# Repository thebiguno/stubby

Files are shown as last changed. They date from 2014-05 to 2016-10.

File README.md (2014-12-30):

Stubby
======

Source Code for Stubby the Hexapod (http://stubby.digitalcave.ca/stubby/ or http://hackaday.io/project/770)

Repository includes AVR source code, KiCAD schematics + routed PCBs, frame design (.dxf for cutting on a scroll saw, laser cutter, CNC, etc), python programs for calibration and control, etc.  Please visit the web pages for more information and build instructions.

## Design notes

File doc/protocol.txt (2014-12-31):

Protocol Info
-------------

Message Structure (bi-directional):
Segment				Length
---------------------------------
Frame start			1 byte (0x7e)
Length				1 byte
Command				1 byte
Payload				0 - 254 bytes
Checksum			1 byte

Commands:
---------
There are four logical message types: 
1) PC initiates a message to Stubby
2) Stubby responds to a message from PC
3) Stubby initiates a message to PC
4) PC responds to a message from Stubby

Message types 1 and 2 comprise the majority of communication.  Message 
types 3 and 4 imply an event-driven programming model.  Initially, we 
do not want to do this as it adds complexity to the new programmer,
however we do not want to preclude this from being added at a later 
date.

Commands have a variable payload.  A description of payloads is below.
Portions in [square brackets] are optional.

Command						Direction				Payload																				Response
-------------------------------------------------------------------------------------------------------------------------------------------------------------
-- General commands
AnnounceControlId			Control -> Stubby		Controller ID; UC = 0x55 ('U'), Processing = 0x50 ('P'), Calibration = 'C', etc		None
SendAcknowledge				Stubby -> Control		Command being ack'd (1 byte)														None
SendComplete				Stubby -> Control		Command completed (1 byte)															None

RequestEnableDebug			Control -> Stubby		Null																				Ack
RequestDisableDebug			Control -> Stubby		Null																				Ack
SendDebug					Stubby -> Control		Variable depending on message, max 254 bytes										None

RequestBattery				Control -> Stubby		Null																				Battery message
SendBattery					Stubby -> Control		1 byte																				None

-- Universal Controller commands
UCButtonPush				Control -> Stubby		Index of button which was just pressed (1 byte)										None
UCButtonRelease				Control -> Stubby		Index of button which was just released (1 byte)									None
UCJoystickMove				Control -> Stubby		Value of all joystick axis (4 bytes, order LX:LY:RX:RY)								None

-- Processing API commands
RequestPowerOn				Control -> Stubby		Null																				Ack
RequestPowerOff				Control -> Stubby		Null																				Ack

RequestMove					Control -> Stubby		Angle (1 byte), Velocity (1 byte), Distance (2 bytes)								Ack + Complete when done
RequestTurn					Control -> Stubby		Angle (1 bytes), Velocity (1 byte)													Ack + Complete when done
RequestTranslate			Control -> Stubby		Amount (3 bytes, order X, Y, Z)														Ack
RequestRotate				Control -> Stubby		Axis (1 byte), Angle (1 byte)														Ack

RequestHeading				Control -> Stubby		Null																				Heading message
SendHeading					Stubby -> Control		Angle (1 byte)																		None

RequestDistance				Control -> Stubby		Null																				Distance message
SendDistance				Stubby -> Control		Distance (2 bytes, MSB first)																	None

RequestOptical				Control -> Stubby		Null																				Optical message
SendOptical					Stubby -> Control		1 byte / sensor (TODO: How many sensors?)											None

RequestSetLED				Control -> Stubby		3 bytes (RGB value)																	Ack

-- Calibration program commands
RequestJointCalibration		Control -> Stubby		Null																				SendJointCalibration message
SendJointCalibration		Either -> Either		18 bytes, ordered LEG0_TIBIA, LEG0_FEMUR, LEG0_COXA, ... LEG5_COXA					None

RequestFootCalibration		Control -> Stubby		Null																				SendFootCalibration message
SendFootCalibration			Either -> Either		18 bytes, ordered LEG0_X, LEG0_Y, LEG0_Z, LEG1_X, ... LEG5_Z						None

RequestMagnetometerCalibration	Control -> Stubby	Null																				SendMagnetometerCalibration message
SendMagnetometerCalibration	Either -> Either		4 bytes (two 16 bit signed integers, MSB first): X offset, Y offset					None
StartMagnetometerCalibration	Control -> Stubby	Null																				Repeated SendMagnetometerCalibration messages

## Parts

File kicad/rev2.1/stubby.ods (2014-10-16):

Id | Designator | Package | Quantity | Designation | Supplier and ref | Unit Cost | Ext Cost | Comments
1 | C17 | C1V8 | 1 | 15000µF | 493-1013-ND | $1.8300 | $1.83
2 | VR3,VR1 | SOT23 | 2 | MCP1702 | MCP1702T-3302E/CBCT-ND | $0.7000 | $1.40
3 | P5,P10 | Male Headers, right angle | 1 |  | S1112E-10-ND | $1.1300 | $1.13 | Digikey is expensive, I get mine in bulk from eBay
4 | P1,P2 | Female Headers, 6 position | 3 | CONN_6 | S7004-ND | $0.8200 | $2.46 | One needed for Xbee and one for Bluetooth
5 | P3 | SIL-10 | 1 | CONN_10 | S5751-10-ND | $1.4800 | $1.48 | Only needed if using Xbee
6 | ZD1 | SOT23 | 1 | ZD 3v3 | BZX84C3V3-FDICT-ND | $0.2000 | $0.20
7 | SW2 | DPDT | 1 | DPDT | 360-2804-ND | $3.7400 | $3.74
8 | S4-S7, P11,JP1,P6,P8 | N/A | 2 | Male headers (straight) | S1011EC-34-ND | $0.8400 | $1.68 | We need about 70 pins total. Digikey is expensive, I get mine in bulk from eBay
9 | IC1 | TQFP44 | 1 | ATMEGA1284-A | ATMEGA1284-AU-ND | $9.2100 | $9.21
10 | R4,R7,R3,R8,R10,R9,R1,R2 | SM0603 | 8 | 1k | 311-1.0KGRCT-ND | $0.0140 | $0.11
11 | C7,C8 | SM0603 | 2 | 20pF | 1276-1187-1-ND | $0.1200 | $0.24
12 | C5,C4,C3,C12,C16,C13,C14,C19 | SM0603 | 8 | 1uF | 587-1242-1-ND | $0.1200 | $0.96
13 | R5,R6 | SM0603 | 2 | 100k | 311-100KGRCT-ND | $0.0140 | $0.03
14 | D2 | LED-0805-MARKED_ANODE | 1 | LED | 475-2832-1-ND | $0.2700 | $0.27
15 | VR2 | SOT23-5 | 1 | NCP1400A | NCP1400ASN50T1GOSCT-ND | $0.9900 | $0.99
16 | C10,C15 | SM1206POL | 2 | 47uF | ATCC-211A-006-476M-TCT-ND | $0.4900 | $0.98
17 | C1 | SM0805 | 1 | 10uF | 1276-3012-1-ND | $0.1900 | $0.19
18 | D1 | POWERDI_123 | 1 | DFLS130L | DFLS130LDICT-ND | $0.5900 | $0.59
19 | L1 | SM1007 | 1 | 22uH | 587-2439-1-ND | $0.3500 | $0.35
20 | D3 | 4-PLCC | 1 | CLVBA-FKA | CLVBA-FKA-CAEDH8BBB7A363CT-ND | $0.6600 | $0.66
21 | SW1 | sw_42_32 | 1 | SW_PUSH | CKN10502CT-ND | $0.3600 | $0.36
22 | X1 | CRYSTAL_SMD_5x3.2 | 1 | CRYSTAL | CTX1164CT-ND | $0.7600 | $0.76
23 | C6 | SM0603 | 1 | 4.7uF | 490-3297-1-ND | $0.1400 | $0.14
24 | C9 | SM0603 | 1 | 0.22uF | 445-1318-1-ND | $0.1200 | $0.12
25 | U1 | LPCC-16 | 1 | HMC5883L | 342-1082-1-ND | $4.2400 | $4.24
26 | C2 | C1V7 | 1 | 2200uF+ | UHM0J222MPD6-ND | $0.5900 | $0.59
27 | C11 | C1V5 | 1 | 470uF | 399-6611-ND | $0.2700 | $0.27
28 | N/A | HC-SR04 Distance Sensor | 1 | N/A | eBay | $2.0000 | $2.00 | Not on Digikey, I got mine on eBay for under $2
 | Total |  |  |  |  |  | $36.98 | Quantity 1 Robot

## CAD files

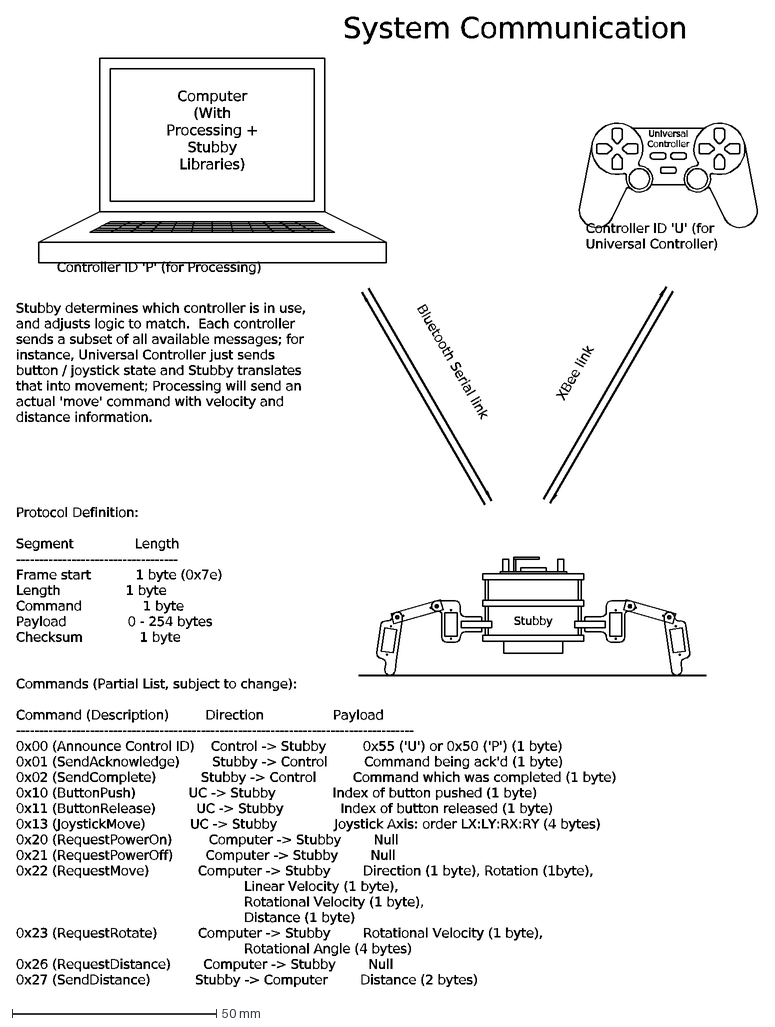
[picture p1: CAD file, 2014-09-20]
doc/System Overview.dxf
Universal Controller
Computer (With Processing + Stubby Libraries)
Stubby
Protocol Definition: Segment Length ----------------------------------- Frame start 1 byte (0x7e) Length 1 byte Command 1 byte Payload 0 - 254 bytes Checksum 1 
Controller ID 'P' (for Processing)
Controller ID 'U' (for Universal Controller)
Bluetooth Serial link
XBee link
Stubby determines which controller is in use, and adjusts logic to match. Each controller sends a subset of all available messages; for instance, Universal Cont
System Communication

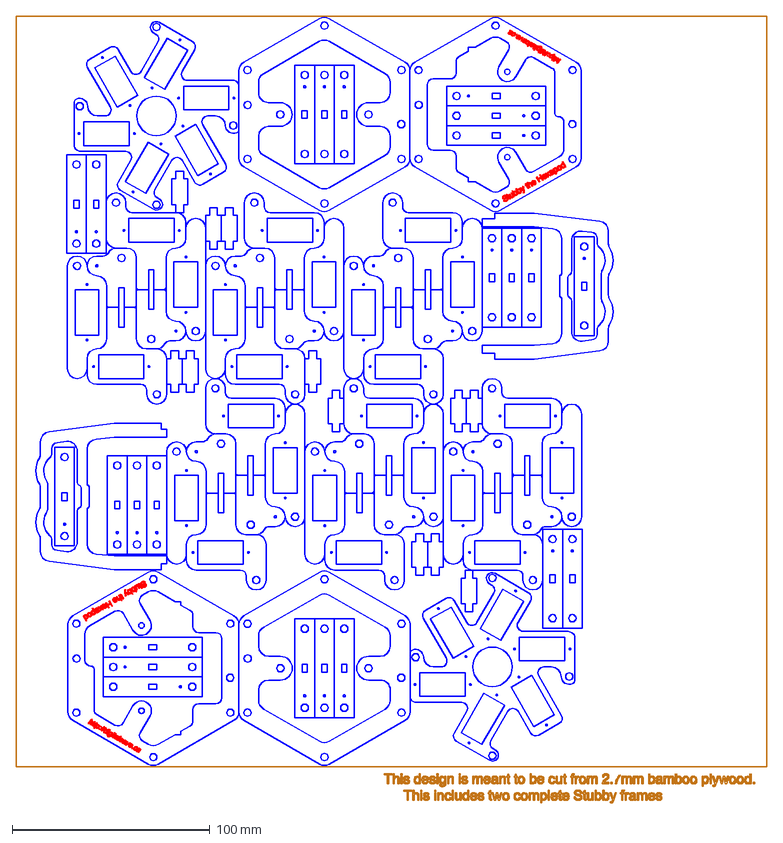
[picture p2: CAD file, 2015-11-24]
frame/frame_3dof_radial_laser.dxf
380.0 x 398.3 mm

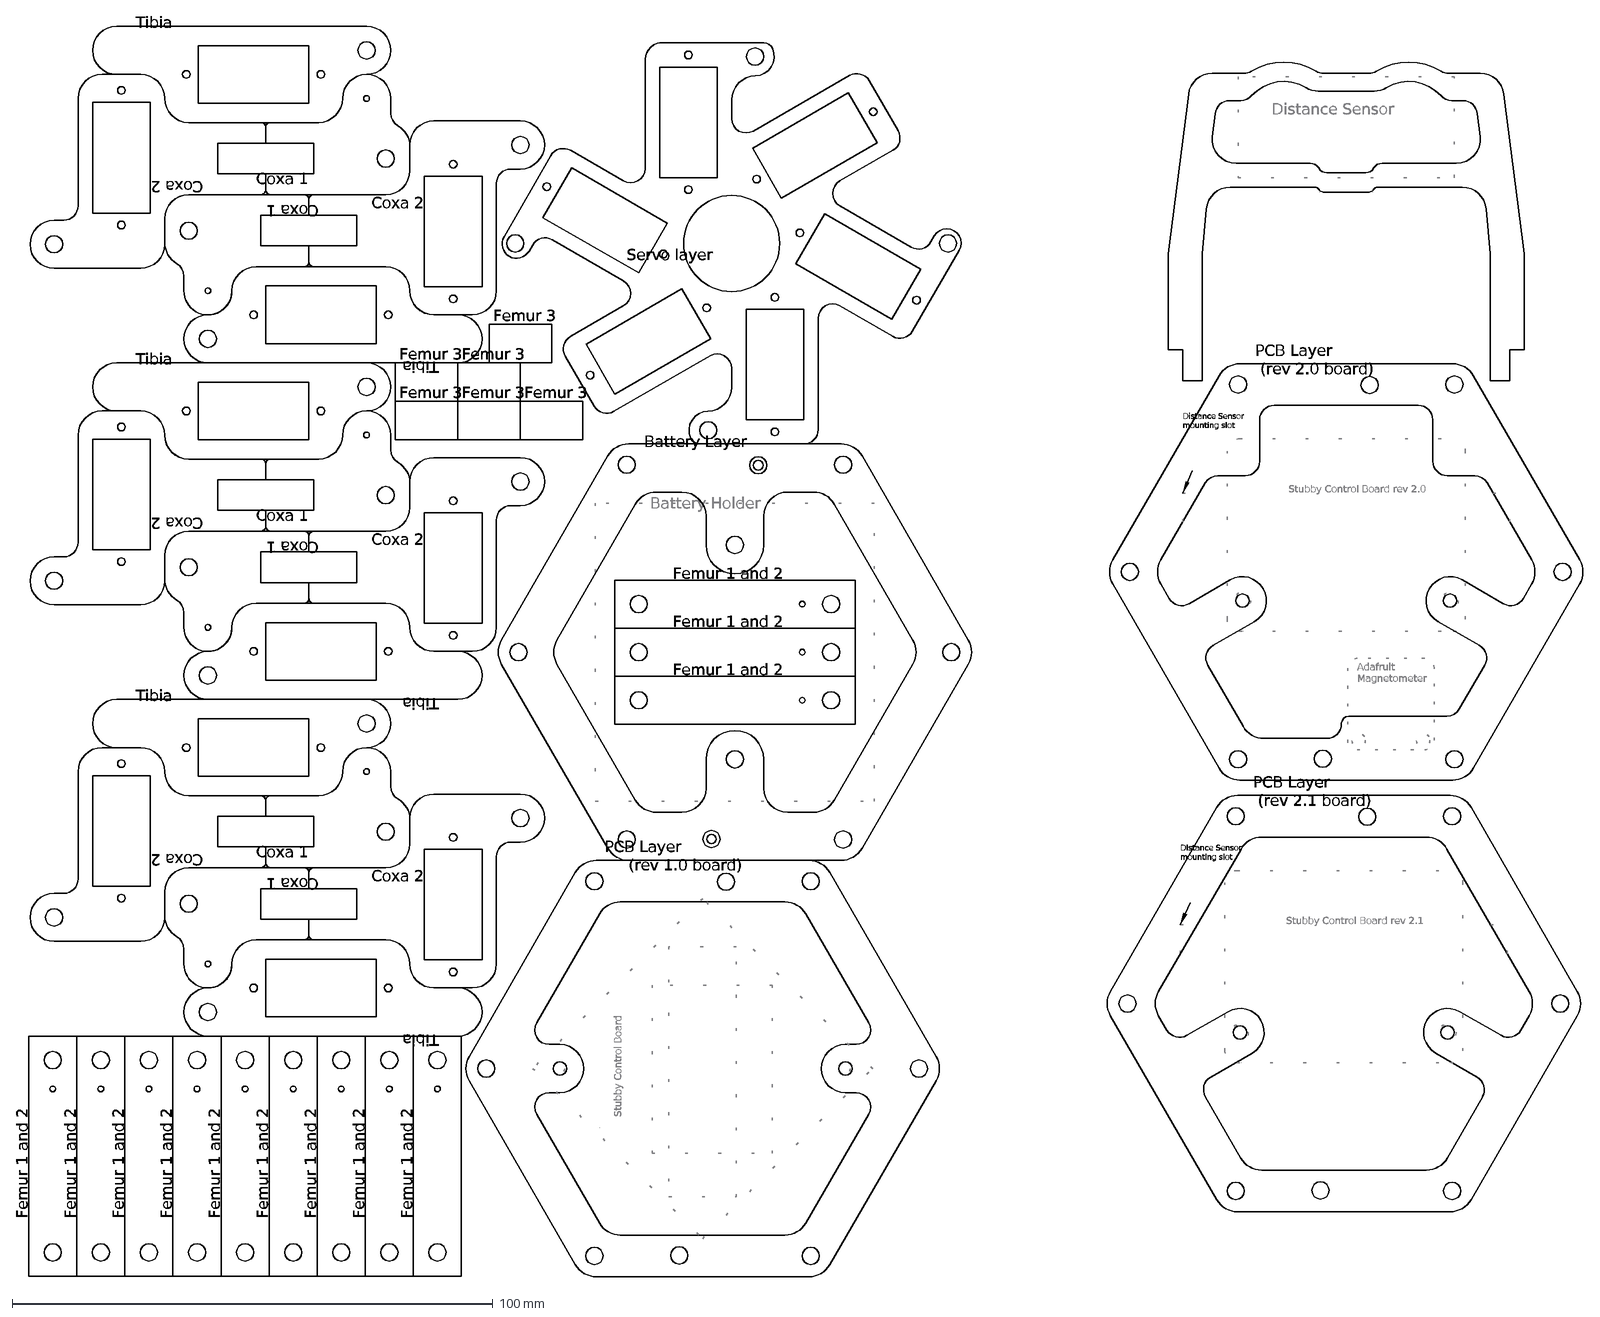
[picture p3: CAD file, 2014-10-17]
frame/frame_3dof_radial.dxf
Femur 1 and 2
Coxa 1
Coxa 2
Tibia
PCB Layer (rev 1.0 board)
Battery Holder
Battery Layer
Servo layer
Femur 3
PCB Layer (rev 2.0 board)
Stubby Control Board rev 2.0
Adafruit Magnetometer
Distance Sensor mounting slot
Distance Sensor
Stubby Control Board
PCB Layer (rev 2.1 board)
Stubby Control Board rev 2.1

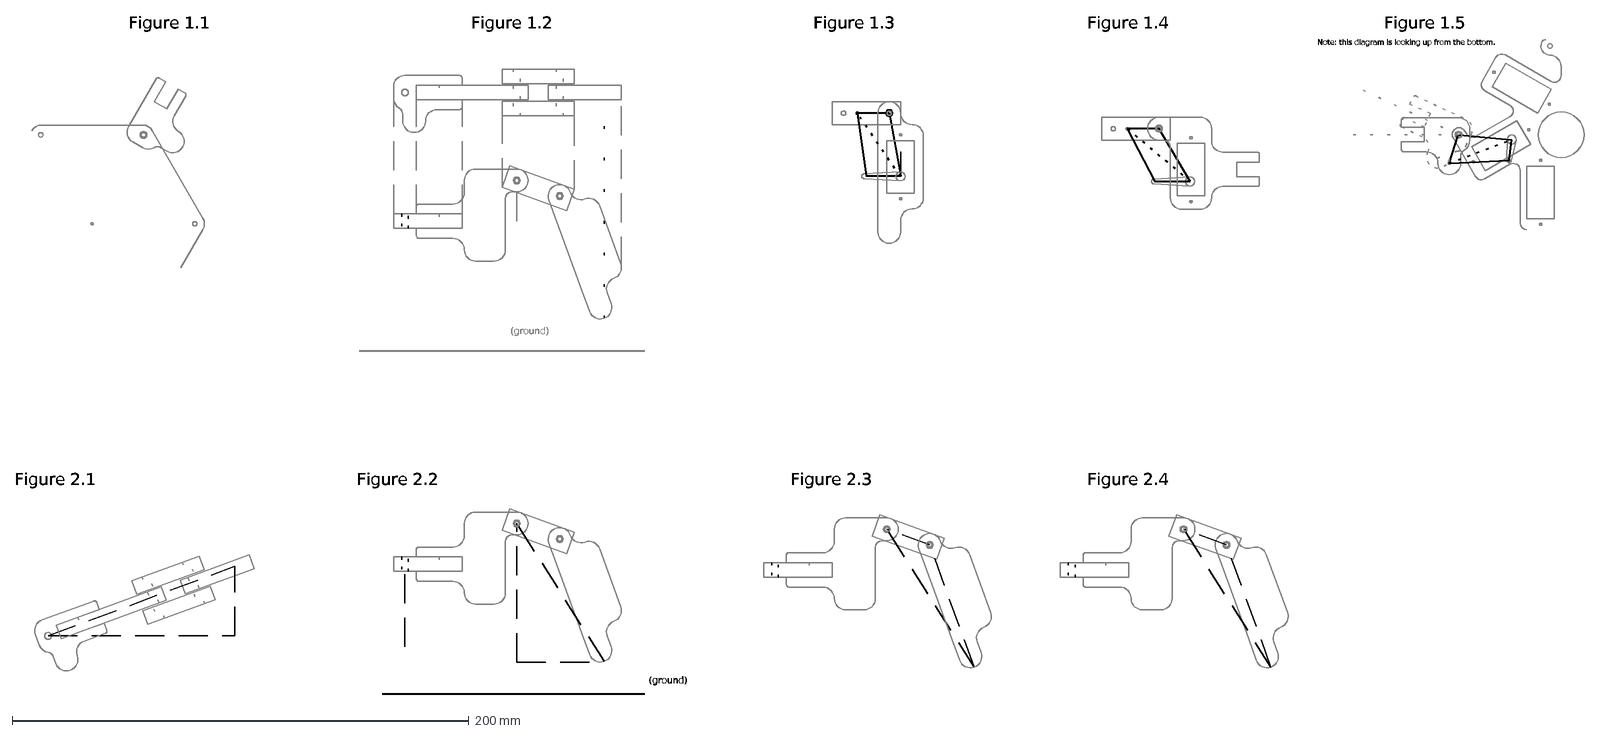
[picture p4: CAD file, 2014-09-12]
frame/frame_3dof_radial_diagrams.dxf
Figure 1.1
(ground)
Figure 1.2
Figure 1.3
Figure 1.4
Figure 2.1
Figure 2.2
Figure 2.3
Figure 2.4
Figure 1.5
Note: this diagram is looking up from the bottom.

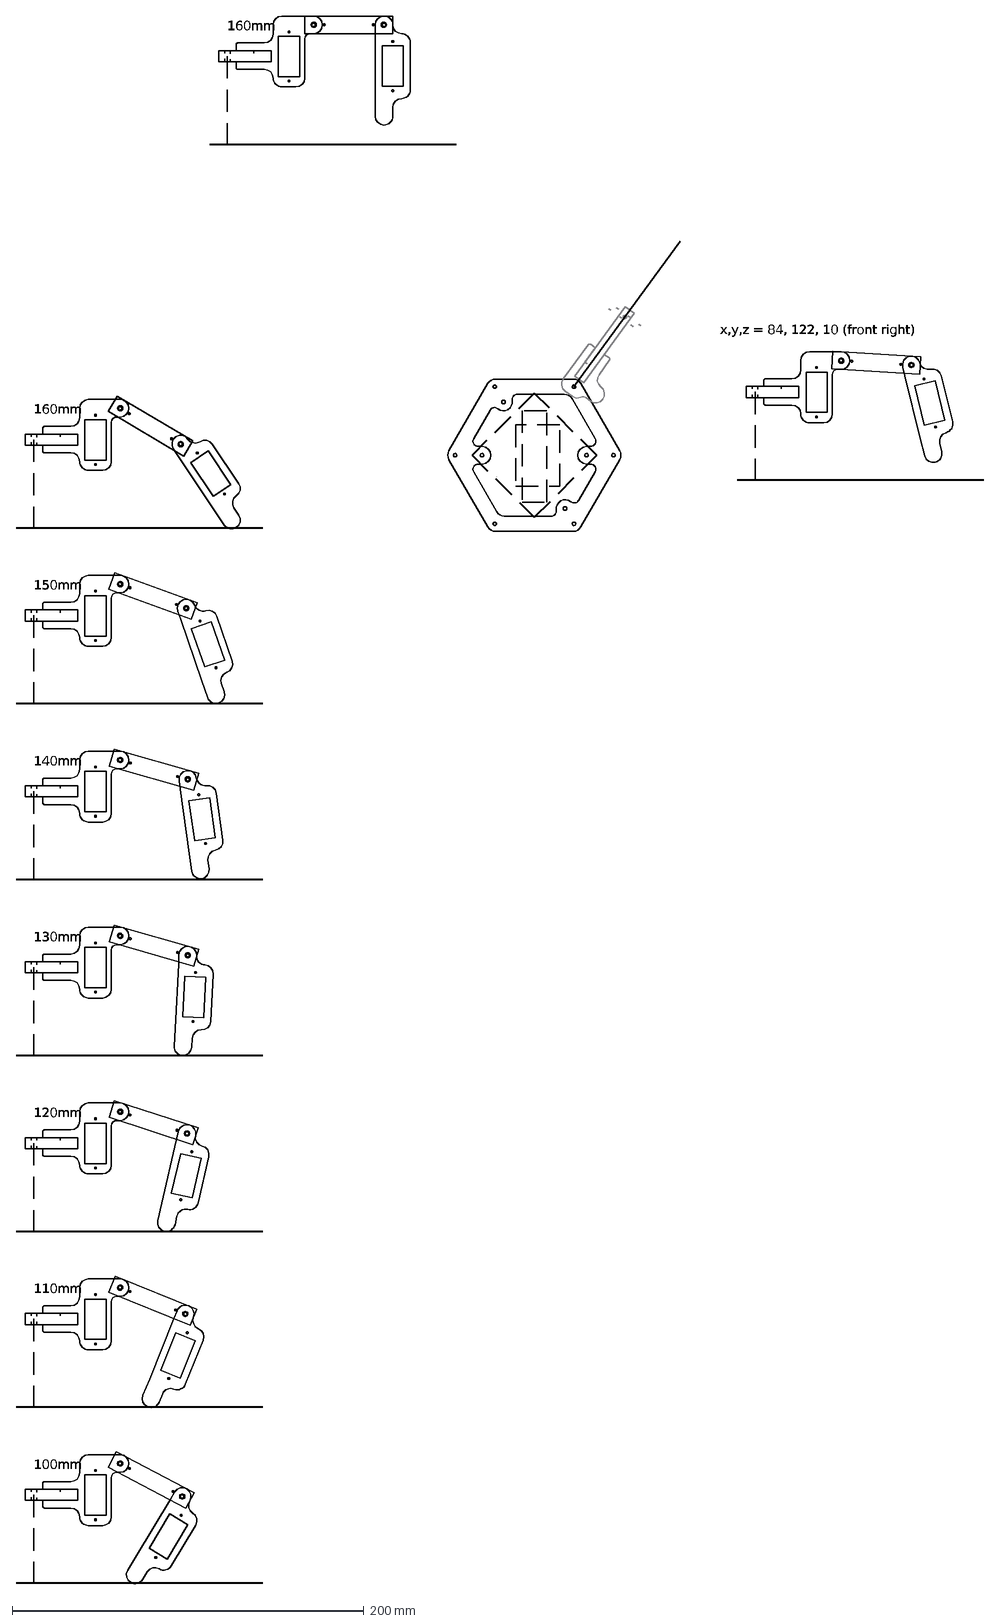
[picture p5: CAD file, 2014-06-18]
frame/frame_3dof_radial_simulation.dxf
150mm
140mm
130mm
120mm
110mm
100mm
160mm
x,y,z = 84, 122, 10 (front right)

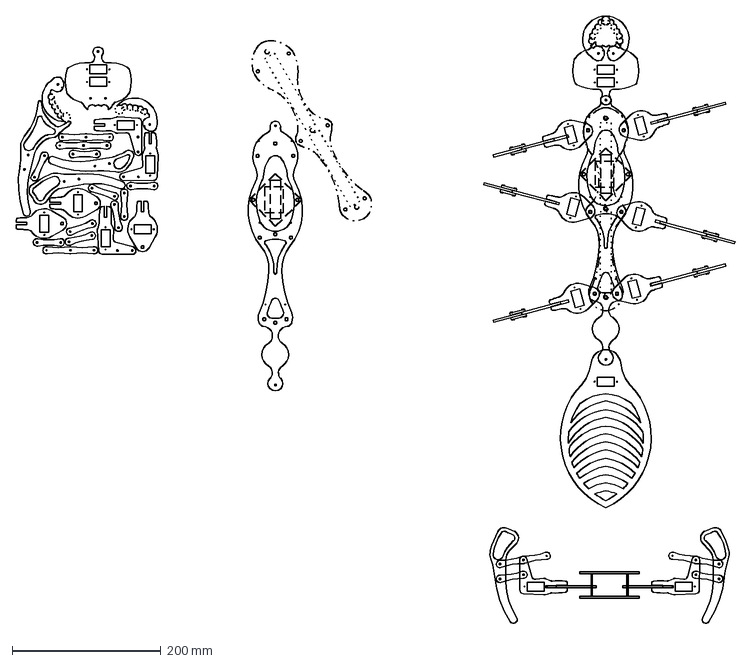
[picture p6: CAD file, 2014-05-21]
frame/frame_2dof_insect.dxf
968.1 x 818.4 mm

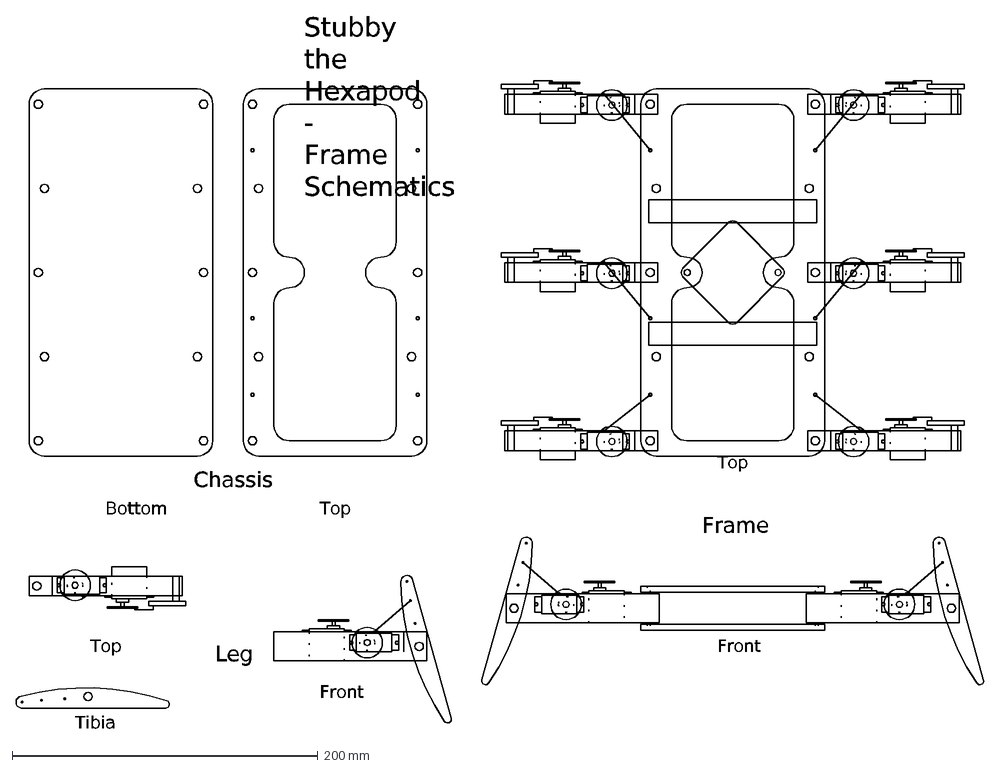
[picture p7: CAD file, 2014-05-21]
frame/frame_2dof_simple.dxf
Chassis
Top
Bottom
Leg
Front
Frame
Tibia
Stubby the Hexapod - Frame Schematics

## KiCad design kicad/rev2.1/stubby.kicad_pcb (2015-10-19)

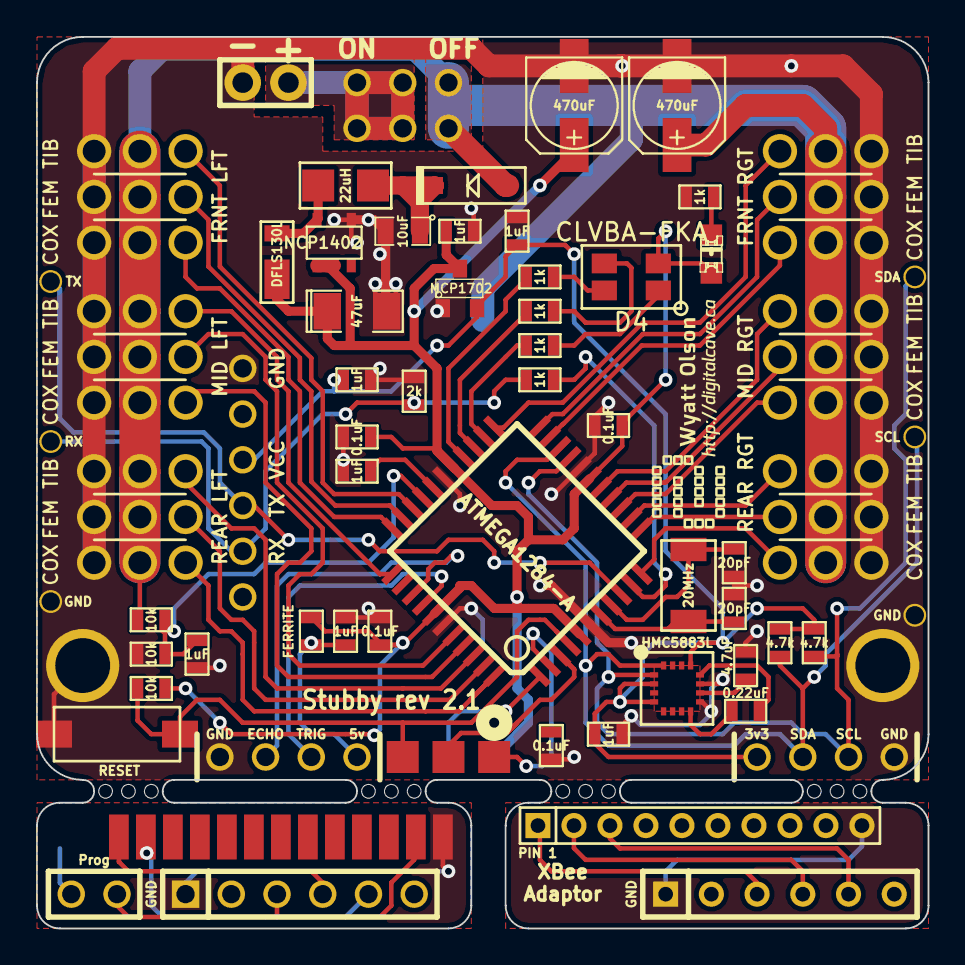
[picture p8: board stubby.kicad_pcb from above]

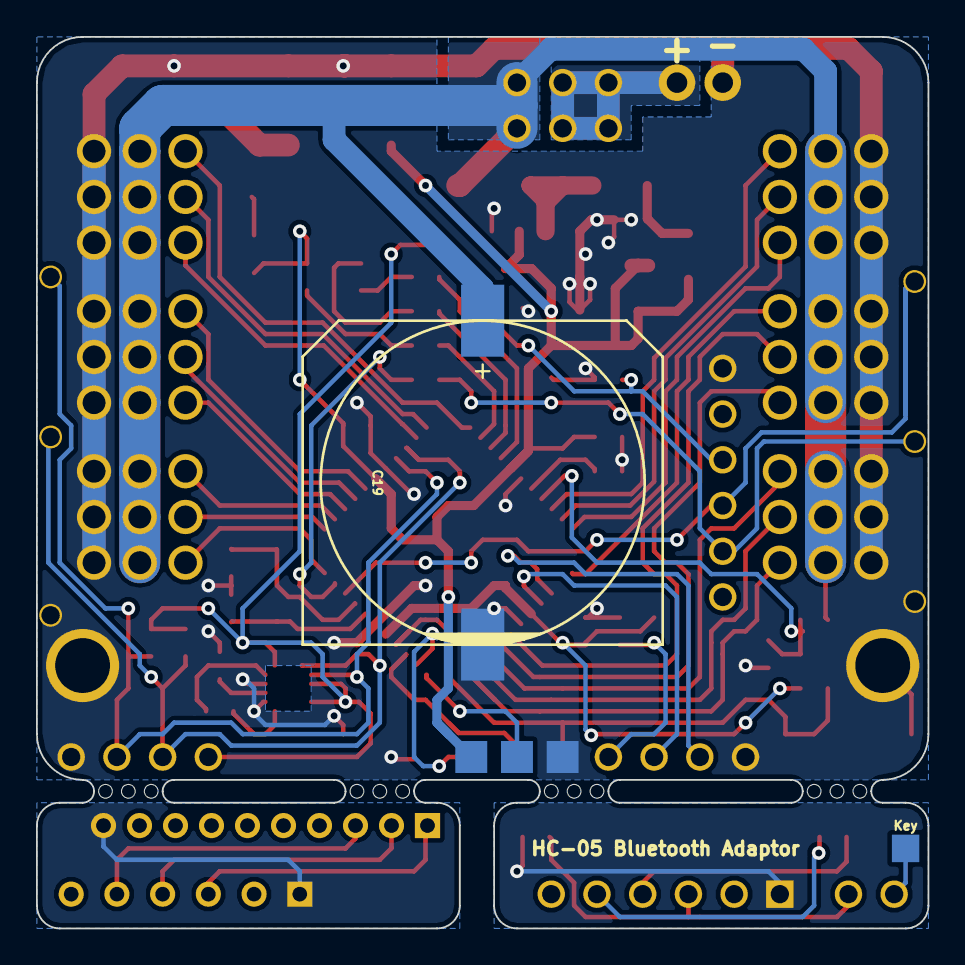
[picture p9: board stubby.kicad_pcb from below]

Board: 2 copper layers, 49.5 x 49.5 mm, 74 parts (2 on the bottom side), 60 nets.

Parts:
1PIN, 1PIN#2, 1PIN#3, 1PIN#4, 1PIN#5, 1PIN#6, 1PIN#7, 1PIN#8: P***; 1pin
C1: 10uF; SM0805
C2, C3, C6, C15, C16, C17, C18: 1uF; SM0603_VALUE
C4: 47uF; SM1206POL
C5, C20: 470uF; c_elec_5x5.3
C7: 4.7uF; SM0603_VALUE
C8, C9: 20pF; SM0603_VALUE
C10: 0.22uF; SM0603_VALUE
C11, C12, C13, C14: 0.1uF; SM0603_VALUE
C19: 6800µF; c_elec_18x18
D1: 1N4148W; SOD-123_DIODE
D2: DFLS130L; POWERDI_123
D3: LED; LED-0805-MARKED_ANODE
D4: CLVBA-FKA; 4-PLCC
IC1: ATMEGA1284-A; TQFP44
L1: 22uH; SM1007
L2: FERRITE; SM0603_VALUE
P1, P6, P11: CONN_6; SIL-6
P2, P10: CONN_4; SIL-4
P3: CONN_13; HC05_Edge
P4: CONN_2; SIL-2
P5: CONN_1; SIL-1
P7: CONN_10; SIL-10
P8: BATT (4.8V-6V); SIL-2
P9: PROG; ISP_EDGE
R1, R2: 4.7k; SM0603_VALUE
R3, R5, R6: 10k; SM0603_VALUE
R4, R7, R9, R10, R11: 1k; SM0603_VALUE
R8: 2k; SM0603_VALUE
S1: FRNT LFT; HEX_LEG
S2: FRNT RGT; HEX_LEG_REVERSE
S3: MID LFT; HEX_LEG
S4: MID RGT; HEX_LEG_REVERSE
S5: REAR LFT; HEX_LEG
S6: REAR RGT; HEX_LEG_REVERSE
SW1: SW_PUSH; SW_6x3
SW2: DPDT
U1: HMC5883L; LPCC-16
VAL: DIGITALCAVE_LOGO_WIDE_SMALL
VR1: MCP1702; SOT23
VR2: NCP1402; SOT23-5
X1: 20MHz; CRYSTAL_SMD_5x3.2
mouse_bites: VAL**; mouse_bites
mouse_bites#2, mouse_bites#3, mouse_bites#4: VAL**; mouse_bites

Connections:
+3.3V: C2.1, C15.1, C18.2, P2.1, P11.3, R1.2, R2.2, U1.2, U1.4, U1.13, VR1.3
+5V: C3.1, C4.1, C5.1, C11.1, C12.1, C13.1, D2.2, D3.1, D4.2, IC1.5, IC1.17, IC1.27, IC1.38, L2.2, P9.2, R3.1, VR1.2, VR2.1, VR2.2
+BATT: C19.1, C20.1, D1.1, R5.1, S1.4, S1.5, S1.6, S2.4, S2.5, S2.6, S3.4, S3.5, S3.6, S4.4, S4.5, S4.6, S5.4, S5.5, S5.6, S6.4, S6.5, S6.6, SW2.3, SW2.6
/ADC_BATTERY_METER: C16.2, IC1.30, R5.2, R6.2
/AREF: C6.2, IC1.29
/AVR_RX: 1PIN#6.1, IC1.9, P11.4
/AVR_TX: IC1.10, R7.1
/BATTERY: P8.1, SW2.1, SW2.2, SW2.4, SW2.5
/BLUETOOTH_GND: P1.1, P3.13
/DIST_ECHO: IC1.36, P10.3
/DIST_TRIG: IC1.37, P10.2
/I2C_SCL: 1PIN#3.1, IC1.19, P2.3, R1.1, U1.1
/I2C_SDA: 1PIN#2.1, IC1.20, P2.2, R2.1, U1.16
/LED_BL: IC1.25, R10.1
/LED_BL_R: D4.3, R10.2
/LED_GR: IC1.26, R9.1
/LED_GR_R: D4.4, R9.2
/LED_RD: IC1.24, R11.1
/LED_RD_R: D4.1, R11.2
/MISO: IC1.2, P9.1
/MODULE_RX: 1PIN#5.1, P11.5, R7.2, R8.2
/MOSI: IC1.1, P9.4
/PWM00: IC1.33, S1.1
/PWM01: IC1.32, S1.2
/PWM02: IC1.31, S1.3
/PWM03: IC1.23, S2.1
/PWM04: IC1.22, S2.2
/PWM05: IC1.21, S2.3
/PWM06: IC1.41, S3.1
/PWM07: IC1.40, S3.2
/PWM08: IC1.34, S3.3
/PWM09: IC1.16, S4.1
/PWM10: IC1.15, S4.2
/PWM11: IC1.14, S4.3
/PWM12: IC1.44, S5.1
/PWM13: IC1.43, S5.2
/PWM14: IC1.42, S5.3
/PWM15: IC1.13, S6.1
/PWM16: IC1.12, S6.2
/PWM17: IC1.11, S6.3
/RESET: IC1.4, P9.5, R3.2, SW1.2
/SCK: IC1.3, P9.3
/XBEE_GND: P6.1, P7.10
/XTAL1: C9.2, IC1.8, X1.1
/XTAL2: C8.2, IC1.7, X1.2
GND: 1PIN.1, 1PIN#4.1, 1PIN#7.1, 1PIN#8.1, C1.2, C2.2, C3.2, C4.2, C5.2, C6.1, C7.2, C8.1, C9.1, C11.2, C12.2, C13.2, C14.2, C15.2, C16.1, C17.2, C18.1, C19.2, C20.2, IC1.6, IC1.18, IC1.28, IC1.39, P2.4, P8.2, P9.6, P10.4, P11.1, R4.1, R6.1, R8.1, S1.7, S1.8, S1.9, S2.7, S2.8, S2.9, S3.7, S3.8, S3.9, S4.7, S4.8, S4.9, S5.7, S5.8, S5.9, S6.7, S6.8, S6.9, SW1.1, U1.9, U1.11, VR1.1, VR2.4
unnamed: C7.1, U1.10
unnamed: C10.1, U1.8
unnamed: C10.2, U1.12
unnamed: D2.1, L1.2, VR2.5
unnamed: C1.1, D1.2, L1.1
unnamed: C17.1, L2.1, P10.1
unnamed: D3.2, R4.2
unnamed: P6.3, P7.1
unnamed: P6.4, P7.2
unnamed: P6.5, P7.3
unnamed: P1.5, P3.2
unnamed: P4.1, P5.1
unnamed: P1.4, P3.1
unnamed: P1.3, P3.12, P4.2

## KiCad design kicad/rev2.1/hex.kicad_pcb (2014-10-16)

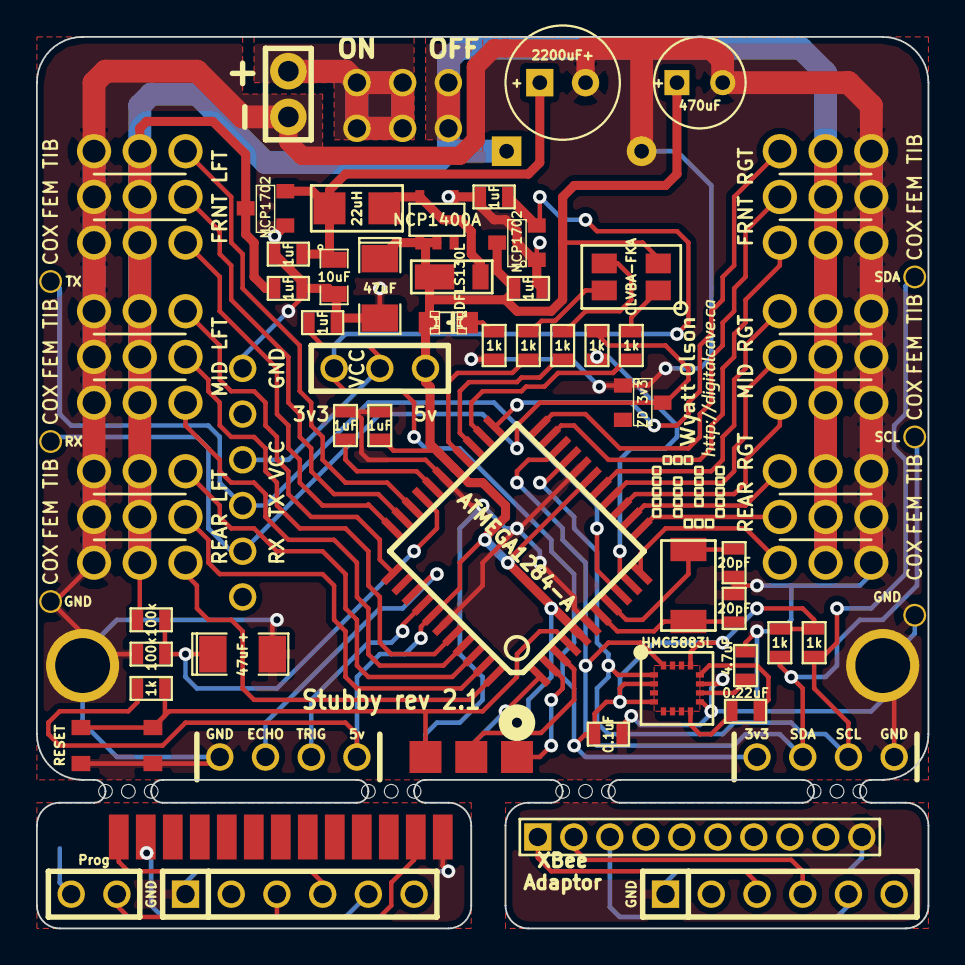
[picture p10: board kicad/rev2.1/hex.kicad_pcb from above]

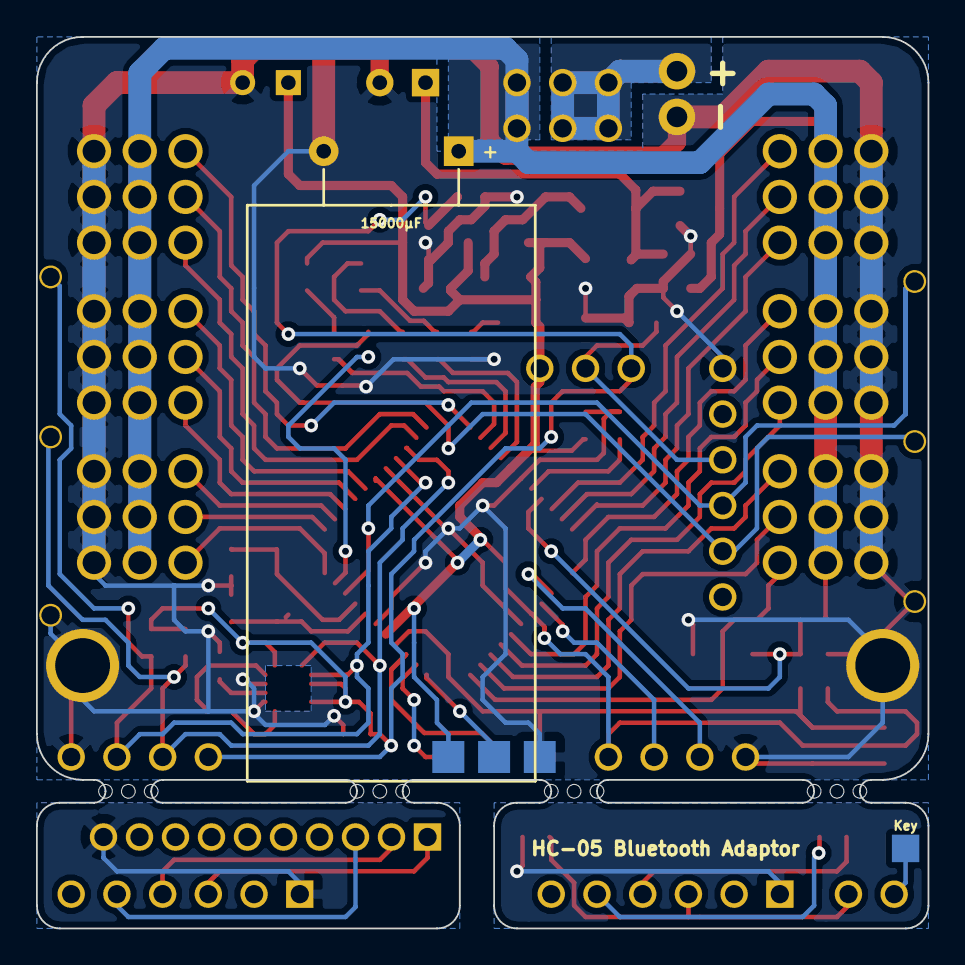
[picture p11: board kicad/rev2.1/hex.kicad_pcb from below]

Board: 2 copper layers, 49.5 x 49.5 mm, 72 parts (2 on the bottom side), 60 nets.

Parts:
1PIN, 1PIN#2, 1PIN#3, 1PIN#4, 1PIN#5, 1PIN#6, 1PIN#7, 1PIN#8: P***; 1pin
C1: 10uF; SM0805
C2: 2200uF+; C1V7
C3, C4, C5, C12, C13, C14, C16: 1uF; SM0603_VALUE
C6: 4.7uF; SM0603_VALUE
C7, C8: 20pF; SM0603_VALUE
C9: 0.22uF; SM0603_VALUE
C10: 47uF; SM1206POL
C11: 470uF; C1V5
C15: 47uF+; SM1206POL
C17: 15000µF; C1V8
C19: 0.1uF; SM0603_VALUE
D1: DFLS130L; POWERDI_123
D2: LED; LED-0805-MARKED_ANODE
D3: CLVBA-FKA; 4-PLCC
IC1: ATMEGA1284-A; TQFP44
JP1: CONN_3; SIL-3
L1: 22uH; SM1007
P1, P2, P11: CONN_6; SIL-6
P3: CONN_10; SIL-10
P4: CONN_13; HC05_Edge
P5, P10: CONN_4; SIL-4
P6: CONN_2; SIL-2
P7: CONN_1; SIL-1
P8: BATT (4.8V-6V); SIL-2
P9: PROG; ISP_EDGE
R1, R2, R3, R4, R7, R8, R9, R10: 1k; SM0603_VALUE
R5, R6: 100k; SM0603_VALUE
S2: FRNT LFT; HEX_LEG
S3: FRNT RGT; HEX_LEG_REVERSE
S4: MID LFT; HEX_LEG
S5: MID RGT; HEX_LEG_REVERSE
S6: REAR LFT; HEX_LEG
S7: REAR RGT; HEX_LEG_REVERSE
SW1: SW_PUSH; sw_42_32
SW2: DPDT
U1: HMC5883L; LPCC-16
VAL: DIGITALCAVE_LOGO_WIDE_SMALL
VR1, VR3: MCP1702; SOT23
VR2: NCP1400A; SOT23-5
X1: CRYSTAL; CRYSTAL_SMD_5x3.2
ZD1: ZD 3v3; SOT23
mouse_bites: VAL**; mouse_bites
mouse_bites#2, mouse_bites#3, mouse_bites#4: VAL**; mouse_bites

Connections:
+3.3V: C13.1, C19.1, JP1.3, P5.1, R1.2, R2.2, U1.2, U1.4, U1.13, VR3.3
+5V: C10.1, C11.1, C12.2, C14.1, D1.2, D2.1, D3.2, IC1.5, IC1.17, IC1.27, IC1.38, JP1.1, P9.2, P10.1, R3.1, VR2.1, VR2.2, VR3.2
+BATT: C4.1, C17.1, R5.1, S2.4, S2.5, S2.6, S3.4, S3.5, S3.6, S4.4, S4.5, S4.6, S5.4, S5.5, S5.6, S6.4, S6.5, S6.6, S7.4, S7.5, S7.6, SW2.3, SW2.6, VR1.2
/ADC_BATTERY_METER: C15.1, IC1.30, R5.2, R6.2
/AREF: C5.2, IC1.29
/AVR_RX: 1PIN#6.1, IC1.9, P11.4
/AVR_TX: IC1.10, R7.1
/BATTERY: P8.1, SW2.1, SW2.2, SW2.4, SW2.5
/BLUETOOTH_GND: P2.1, P4.13
/DIST_ECHO: IC1.36, P10.3
/DIST_TRIG: IC1.37, P10.2
/I2C_SCL: 1PIN#3.1, IC1.19, P5.3, R1.1, U1.1
/I2C_SDA: 1PIN#2.1, IC1.20, P5.2, R2.1, U1.16
/LED_BL: IC1.25, R9.1
/LED_BL_R: D3.3, R9.2
/LED_GR: IC1.26, R8.1
/LED_GR_R: D3.4, R8.2
/LED_RD: IC1.24, R10.1
/LED_RD_R: D3.1, R10.2
/MISO: IC1.2, P9.1
/MODULE_RX: 1PIN#5.1, P11.5, R7.2, ZD1.2
/MOSI: IC1.1, P9.4
/PWM00: IC1.33, S2.1
/PWM01: IC1.32, S2.2
/PWM02: IC1.31, S2.3
/PWM03: IC1.23, S3.1
/PWM04: IC1.22, S3.2
/PWM05: IC1.21, S3.3
/PWM06: IC1.41, S4.1
/PWM07: IC1.40, S4.2
/PWM08: IC1.34, S4.3
/PWM09: IC1.16, S5.1
/PWM10: IC1.15, S5.2
/PWM11: IC1.14, S5.3
/PWM12: IC1.44, S6.1
/PWM13: IC1.43, S6.2
/PWM14: IC1.42, S6.3
/PWM15: IC1.13, S7.1
/PWM16: IC1.12, S7.2
/PWM17: IC1.11, S7.3
/RESET: IC1.4, P9.5, R3.2, SW1.2
/SCK: IC1.3, P9.3
/XBEE_GND: P1.1, P3.10
/XTAL1: C8.2, IC1.8, X1.1
/XTAL2: C7.2, IC1.7, X1.2
GND: 1PIN.1, 1PIN#4.1, 1PIN#7.1, 1PIN#8.1, C1.2, C2.2, C3.2, C4.2, C5.1, C6.2, C7.1, C8.1, C10.2, C11.2, C12.1, C13.2, C14.2, C15.2, C16.1, C17.2, C19.2, IC1.6, IC1.18, IC1.28, IC1.39, P5.4, P8.2, P9.6, P10.4, P11.1, R4.1, R6.1, S2.7, S2.8, S2.9, S3.7, S3.8, S3.9, S4.7, S4.8, S4.9, S5.7, S5.8, S5.9, S6.7, S6.8, S6.9, S7.7, S7.8, S7.9, SW1.1, U1.9, U1.11, VR1.1, VR2.4, VR3.1, ZD1.1
unnamed: P1.5, P3.3
unnamed: P1.4, P3.2
unnamed: P1.3, P3.1
unnamed: P2.5, P4.2
unnamed: P2.4, P4.1
unnamed: P2.3, P4.12, P6.2
unnamed: C16.2, JP1.2, P11.3
unnamed: D1.1, L1.2, VR2.5
unnamed: P6.1, P7.1
unnamed: C9.1, U1.8
unnamed: C9.2, U1.12
unnamed: D2.2, R4.2
unnamed: C6.1, U1.10
unnamed: C1.1, C2.1, C3.1, L1.1, VR1.3

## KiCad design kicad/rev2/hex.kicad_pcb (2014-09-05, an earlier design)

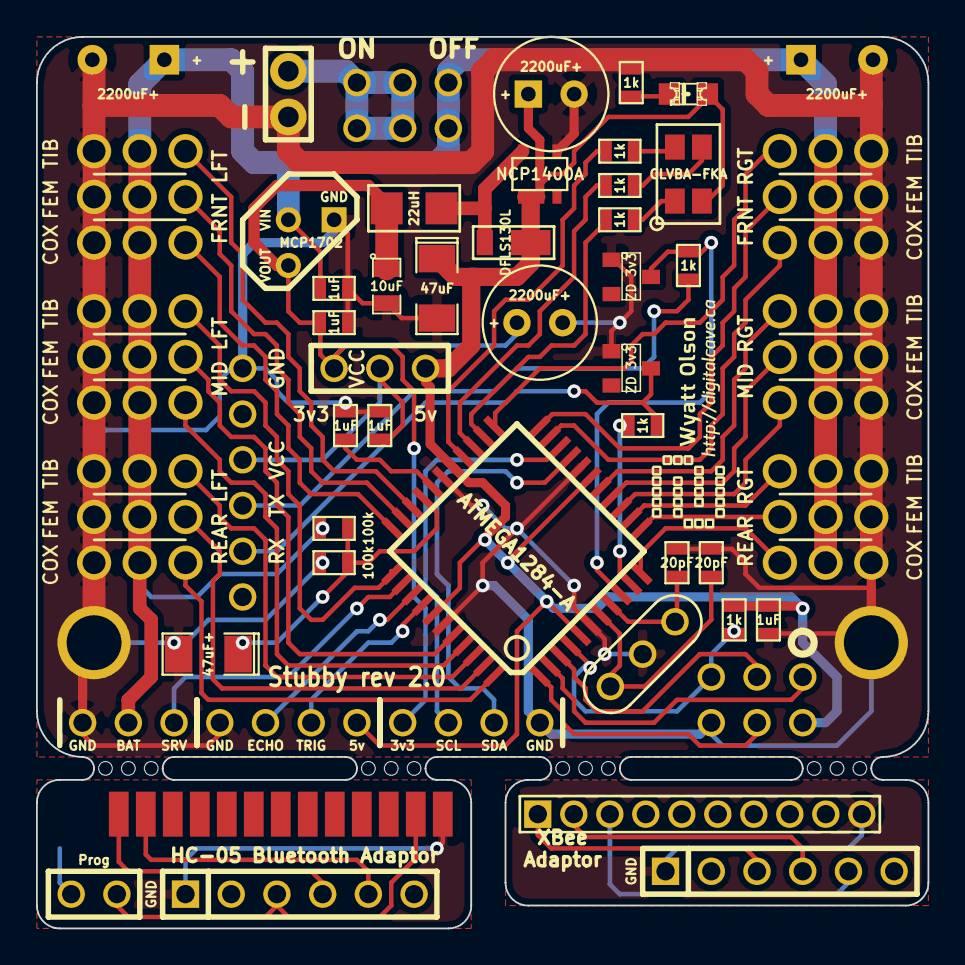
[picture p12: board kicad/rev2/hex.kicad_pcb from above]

Board: 2 copper layers, 49.5 x 49.5 mm, 60 parts (1 on the bottom side), 58 nets.

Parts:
1PIN, 1PIN#2: P***; 1pin
C1, C8: 2200uF+; C1V7
C2, C3, C9, C13, C14: 1uF; SM0603_VALUE
C4, C5: 2200uF+; C1V8
C6: 10uF; SM0805
C7: 47uF; SM1206POL
C10: 47uF+; SM1206POL
C11, C12: 20pF; SM0603_VALUE
D1: DFLS130L; POWERDI_123
D2: LED; LED-0805-MARKED_ANODE
D3: CLVBA-FKA; 4-PLCC
IC1: ATMEGA1284-A; TQFP44
JP1: CONN_3; SIL-3
L1: 22uH; SM1007
P1: BATT (4.8V-6V); SIL-2
P2: PROG; ISP
P3: CONN_10; SIL-10
P4, P6, P8: CONN_6; SIL-6
P5: CONN_13; HC05_Edge
P7: CONN_1; SIL-1
P9: CONN_2; SIL-2
P10, P11: CONN_4; SIL-4
R1, R4, R5, R6, R7, R8, R9: 1k; SM0603_VALUE
R2, R3: 100k; SM0603_VALUE
S1: FRNT LFT; HEX_LEG
S2: FRNT RGT; HEX_LEG_REVERSE
S3: MID LFT; HEX_LEG
S4: MID RGT; HEX_LEG_REVERSE
S5: REAR LFT; HEX_LEG
S6: REAR RGT; HEX_LEG_REVERSE
S7: CONN_3; SIL-3
SW1: DPDT
VAL: DIGITALCAVE_LOGO_WIDE_SMALL
VR1: MCP1702; TO92
VR2: NCP1400A; SOT23-5
X1: CRYSTAL_RESONATOR
ZD1, ZD2: ZD 3v3; SOT23
mouse_bites: VAL**; mouse_bites
mouse_bites#2, mouse_bites#3, mouse_bites#4: VAL**; mouse_bites

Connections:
+3.3V: C1.1, C2.1, C6.1, JP1.3, L1.1, P10.1, VR1.3
+5V: C7.1, C8.1, C9.2, D1.2, D2.1, D3.2, IC1.5, IC1.17, IC1.27, IC1.38, JP1.1, P2.2, P11.1, R4.1, VR2.1, VR2.2
+BATT: C3.1, C4.1, C5.1, R2.1, S1.4, S1.5, S1.6, S2.4, S2.5, S2.6, S3.4, S3.5, S3.6, S4.4, S4.5, S4.6, S5.4, S5.5, S5.6, S6.4, S6.5, S6.6, S7.2, SW1.3, SW1.6, VR1.2
/ADC_BATTERY_METER: C10.1, IC1.30, R2.2, R3.2
/AREF: C13.2, IC1.29
/AVR_RX: IC1.9, R9.1, ZD1.2
/AVR_TX: IC1.10, R8.1
/BATTERY: P1.1, SW1.1, SW1.2, SW1.4, SW1.5
/BLUETOOTH_GND: P5.13, P8.1
/DIST_ECHO: IC1.36, P11.3
/DIST_SERVO: IC1.35, S7.3
/DIST_TRIG: IC1.37, P11.2
/I2C_SCL: IC1.19, P10.3
/I2C_SDA: IC1.20, P10.2
/LED_BL: IC1.25, R6.1
/LED_BL_R: D3.3, R6.2
/LED_GR: IC1.26, R5.1
/LED_GR_R: D3.4, R5.2
/LED_RD: IC1.24, R7.1
/LED_RD_R: D3.1, R7.2
/MISO: IC1.2, P2.1
/MOSI: IC1.1, P2.4
/PWM00: IC1.33, S1.1
/PWM01: IC1.32, S1.2
/PWM02: IC1.31, S1.3
/PWM03: IC1.23, S2.1
/PWM04: IC1.22, S2.2
/PWM05: IC1.21, S2.3
/PWM06: IC1.41, S3.1
/PWM07: IC1.40, S3.2
/PWM08: IC1.34, S3.3
/PWM09: IC1.16, S4.1
/PWM10: IC1.15, S4.2
/PWM11: IC1.14, S4.3
/PWM12: IC1.44, S5.1
/PWM13: IC1.43, S5.2
/PWM14: IC1.42, S5.3
/PWM15: IC1.13, S6.1
/PWM16: IC1.12, S6.2
/PWM17: IC1.11, S6.3
/RESET: IC1.4, P2.5, R4.2
/SCK: IC1.3, P2.3
/XBEE_GND: P3.10, P4.1
/XTAL1: C12.2, IC1.8, X1.1
/XTAL2: C11.2, IC1.7, X1.2
GND: 1PIN.1, 1PIN#2.1, C1.2, C2.2, C3.2, C4.2, C5.2, C6.2, C7.2, C8.2, C9.1, C10.2, C11.1, C12.1, C13.1, C14.1, IC1.6, IC1.18, IC1.28, IC1.39, P1.2, P2.6, P6.1, P10.4, P11.4, R1.2, R3.1, S1.7, S1.8, S1.9, S2.7, S2.8, S2.9, S3.7, S3.8, S3.9, S4.7, S4.8, S4.9, S5.7, S5.8, S5.9, S6.7, S6.8, S6.9, S7.1, VR1.1, VR2.4, X1.3, ZD1.1, ZD2.1
unnamed: P5.2, P8.5
unnamed: P5.1, P8.4
unnamed: P3.3, P4.5
unnamed: D1.1, L1.2, VR2.5
unnamed: P7.1, P9.1
unnamed: P5.12, P8.3, P9.2
unnamed: P3.2, P4.4
unnamed: P3.1, P4.3
unnamed: P6.4, R9.2
unnamed: P6.5, R8.2, ZD2.2
unnamed: C14.2, JP1.2, P6.3
unnamed: D2.2, R1.1

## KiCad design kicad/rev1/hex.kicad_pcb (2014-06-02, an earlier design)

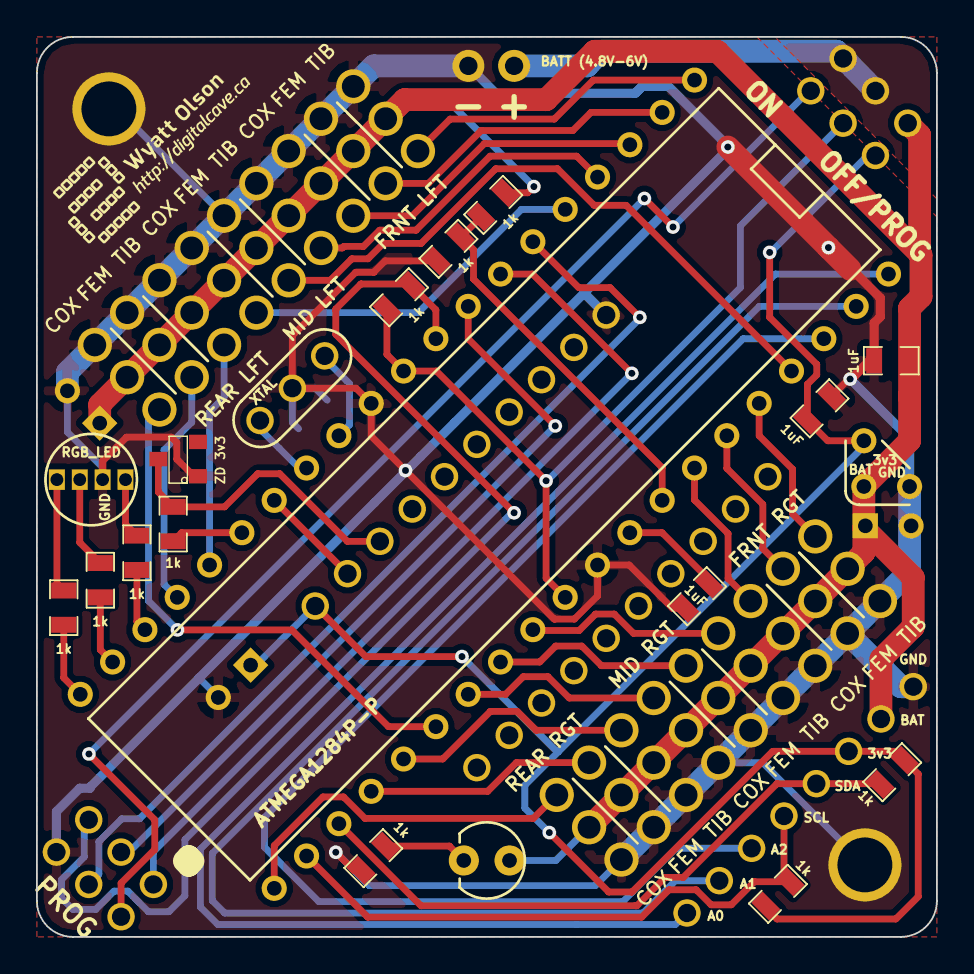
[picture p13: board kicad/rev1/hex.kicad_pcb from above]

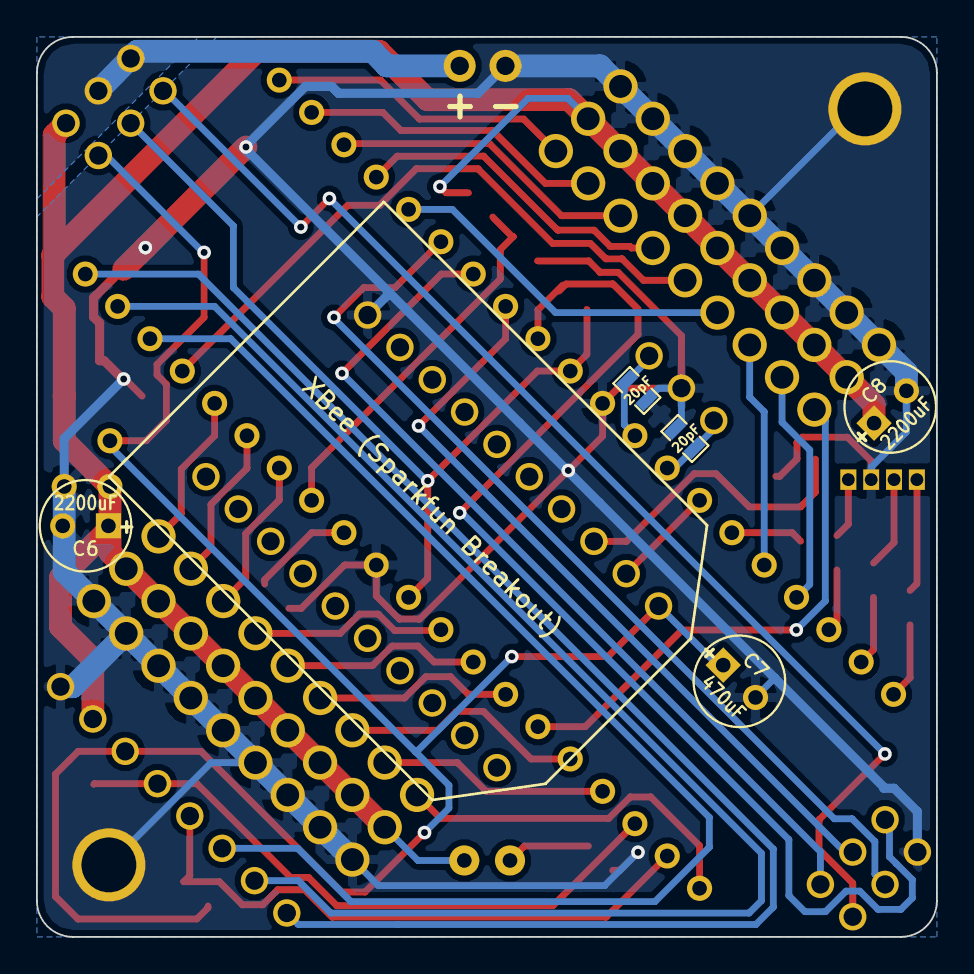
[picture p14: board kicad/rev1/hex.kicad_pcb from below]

Board: 2 copper layers, 50.0 x 50.0 mm, 38 parts (6 on the bottom side), 47 nets.

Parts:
1PIN, 1PIN#2: P***; 1pin
C1, C2, C3: 1uF; SM0805
C4, C5: 20pF; SM0603_Capa
C6, C8: 2200uF; C1V5
C7: 470uF; C1V5
D1: LED; LED-5MM
D2: RGB_LED; LED_RGB
IC1: ATMEGA1284P-P; DIP-40__600
K1: XTAL; PIN_ARRAY_3X1
P1: PROG; pin_array_3x2
P2: BATT (4.8V-6V); PIN_ARRAY_2X1
P3: CONN_8; PIN_ARRAY_8x1
R1, R2, R3, R4, R5, R6, R7, R8, R9, R10: 1k; SM0805
S1: FRNT LFT; HEX_LEG
S2: FRNT RGT; HEX_LEG_REVERSE
S3: MID LFT; HEX_LEG
S4: MID RGT; HEX_LEG_REVERSE
S5: REAR LFT; HEX_LEG
S6: REAR RGT; HEX_LEG_REVERSE
SW1: DPDT
VAL: DIGITALCAVE_LOGO_WIDE_SMALL
VR1: MCP1702; TO92
X1: XBee (Sparkfun Breakout); XBEE_SPARKFUN_BREAKOUT
ZD1: ZD 3v3; SOT23

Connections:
+3.3V: C3.1, C7.1, P3.6, R7.1, R8.1, SW1.6, VR1.3, X1.1
+6V: P2.1, SW1.1, SW1.2
/ADC0: IC1.40, P3.1
/ADC1: IC1.39, P3.2
/ADC2: IC1.38, P3.3
/ADC_BATTERY_METER: IC1.33, R2.2, R3.2
/AREF: C1.2, IC1.32
/AVR_RX: IC1.14, X1.2
/AVR_TX: R9.2, X1.3, ZD1.2
/I2C_SCL: IC1.22, P3.4, R8.2
/I2C_SDA: IC1.23, P3.5, R7.2
/LED_BL: IC1.19, R6.1
/LED_BL_R: D2.3, R6.2
/LED_GR: IC1.20, R5.1
/LED_GR_R: D2.4, R5.2
/LED_RD: IC1.18, R4.1
/LED_RD_R: D2.1, R4.2
/MISO: IC1.7, P1.1
/MOSI: IC1.6, P1.4
/PWM00: IC1.3, S1.1
/PWM01: IC1.2, S1.2
/PWM02: IC1.1, S1.3
/PWM03: IC1.36, S2.1
/PWM04: IC1.35, S2.2
/PWM05: IC1.34, S2.3
/PWM06: IC1.5, S3.1
/PWM07: IC1.37, S3.2
/PWM08: IC1.4, S3.3
/PWM09: IC1.29, S4.1
/PWM10: IC1.28, S4.2
/PWM11: IC1.27, S4.3
/PWM12: IC1.26, S5.1
/PWM13: IC1.17, S5.2
/PWM14: IC1.16, S5.3
/PWM15: IC1.25, S6.1
/PWM16: IC1.24, S6.2
/PWM17: IC1.21, S6.3
/RESET: IC1.9, P1.5, R1.1
/SCK: IC1.8, P1.3
/SWITCHED_BATTERY: C2.2, C6.1, C8.1, D1.1, P3.7, R2.1, S1.4, S1.5, S1.6, S2.4, S2.5, S2.6, S3.4, S3.5, S3.6, S4.4, S4.5, S4.6, S5.4, S5.5, S5.6, S6.4, S6.5, S6.6, SW1.3, VR1.2
/VCC_AVR: IC1.10, IC1.30, R1.2, SW1.5
/VCC_PROG: P1.2, SW1.4
/XTAL1: C5.2, IC1.13, K1.1
/XTAL2: C4.2, IC1.12, K1.3
GND: 1PIN.1, 1PIN#2.1, C1.1, C2.1, C3.2, C4.1, C5.1, C6.2, C7.2, C8.2, D2.2, IC1.11, IC1.31, K1.2, P1.6, P2.2, P3.8, R3.1, R10.2, S1.7, S1.8, S1.9, S2.7, S2.8, S2.9, S3.7, S3.8, S3.9, S4.7, S4.8, S4.9, S5.7, S5.8, S5.9, S6.7, S6.8, S6.9, VR1.1, X1.10, ZD1.1
unnamed: D1.2, R10.1
unnamed: IC1.15, R9.1

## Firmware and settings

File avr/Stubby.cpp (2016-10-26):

#include "Stubby.h"

#include "controllers/calibration.h"
#include "controllers/processing.h"
#include "controllers/universal_controller.h"
#include "gait/gait.h"
#include "hardware/magnetometer.h"
#include "hardware/servo.h"
#include "hardware/status.h"
#include "hardware/timer2.h"
#include "types/Point.h"
#include "util/math.h"

#include "Leg.h"


//Set up the leg objects, including servo details and mounting angle.  Leg indices follows
// // DIP numbering format, starting at front left and proceeding counter clockwise around.
Leg legs[LEG_COUNT] = {
#if PCB_REVISION == 1
	Leg(FRONT_LEFT,		&PORTB, PORTB0, &PORTB, PORTB1, &PORTB, PORTB2, 2 * LEG_MOUNTING_ANGLE, Point(-60, 104, 0)),
	Leg(MIDDLE_LEFT,	&PORTB, PORTB3, &PORTA, PORTA3, &PORTB, PORTB4, 3 * LEG_MOUNTING_ANGLE, Point(-120, 0, 0)),
	Leg(REAR_LEFT,		&PORTD, PORTD2, &PORTD, PORTD3, &PORTC, PORTC4, 4 * LEG_MOUNTING_ANGLE, Point(-60, -104, 0)),
	Leg(REAR_RIGHT,		&PORTC, PORTC3, &PORTC, PORTC2, &PORTD, PORTD7, 5 * LEG_MOUNTING_ANGLE, Point(60, -104, 0)),
	Leg(MIDDLE_RIGHT,	&PORTC, PORTC7, &PORTC, PORTC6, &PORTC, PORTC5, 0 * LEG_MOUNTING_ANGLE, Point(120, 0, 0)),
	Leg(FRONT_RIGHT,	&PORTA, PORTA4, &PORTA, PORTA5, &PORTA, PORTA6, 1 * LEG_MOUNTING_ANGLE, Point(60, 104, 0))
#elif PCB_REVISION == 2
	Leg(FRONT_LEFT,		&PORTA, PORTA6, &PORTA, PORTA5, &PORTA, PORTA4, 2 * LEG_MOUNTING_ANGLE, Point(-60, 104, 0)),
	Leg(MIDDLE_LEFT,	&PORTA, PORTA3, &PORTB, PORTB0, &PORTB, PORTB1, 3 * LEG_MOUNTING_ANGLE, Point(-120, 0, 0)),
	Leg(REAR_LEFT,		&PORTB, PORTB2, &PORTB, PORTB3, &PORTB, PORTB4, 4 * LEG_MOUNTING_ANGLE, Point(-60, -104, 0)),
	Leg(REAR_RIGHT,		&PORTD, PORTD4, &PORTD, PORTD3, &PORTD, PORTD2, 5 * LEG_MOUNTING_ANGLE, Point(60, -104, 0)),
	Leg(MIDDLE_RIGHT,	&PORTD, PORTD7, &PORTD, PORTD6, &PORTD, PORTD5, 0 * LEG_MOUNTING_ANGLE, Point(120, 0, 0)),
	Leg(FRONT_RIGHT,	&PORTC, PORTC4, &PORTC, PORTC3, &PORTC, PORTC2, 1 * LEG_MOUNTING_ANGLE, Point(60, 104, 0))
#else
	#error Unsupported PCB_REVISION value.
#endif
};

//Stubby state variables
static volatile uint8_t power = 0x00;					//0 is off, 1 is on
volatile uint8_t controller = 0x00;						//0 is no controller, 1 is Universal Controller, 2 is Processing API, 3 is Calibration API
volatile uint8_t debug = 0x00;							//0 is no debug, 1 is show debug
volatile uint8_t pending_acknowledge = 0x00;			//When set, we will send a message in the delay code
volatile uint8_t pending_complete = 0x00;				//When set, we will send a message in the delay code

int main (void){
	wdt_enable(WDTO_2S);
	
	servo_init(legs);
	serial_init_b(38400);
	battery_init();
	magnetometer_init();
	distance_init();
	timer2_init();

	while (1){
		wdt_reset();

		if (controller == CONTROLLER_UC){
			uc_command_executor();
		}
		else if (controller == CONTROLLER_PROCESSING){
			processing_command_executor();
		}
		else if (controller == CONTROLLER_CALIBRATION){
			calibration_command_executor();
		}
		
		delay_ms(10);
	}
}

uint8_t get_power(){
	return power;
}
void set_power(uint8_t _power){
	power = _power;
}
uint8_t get_controller(){
	return controller;
}

void doAcknowledgeCommand(uint8_t command){
	pending_acknowledge = command;
}

void doCompleteCommand(uint8_t command){
	pending_complete = command;
}

void doSendDebug(char* message){
	if (debug){
		protocol_send_message(MESSAGE_SEND_DEBUG, (uint8_t*) message, strlen(message));
	}
}

void doResetLegs(){
	for (uint8_t l = 0; l < LEG_COUNT; l+=2){
		legs[l].setOffset(Point(0,0,30));
	}
	pwm_apply_batch();
	delay_ms(200);

	for (uint8_t l = 0; l < LEG_COUNT; l+=2){
		legs[l].setOffset(Point(0,0,0));
	}
	pwm_apply_batch();
	delay_ms(200);

	for (uint8_t l = 1; l < LEG_COUNT; l+=2){
		legs[l].setOffset(Point(0,0,30));
	}
	pwm_apply_batch();
	delay_ms(200);

	for (uint8_t l = 1; l < LEG_COUNT; l+=2){
		legs[l].setOffset(Point(0,0,0));
	}
	pwm_apply_batch();
	delay_ms(200);
}

/*
 * Called from ISR; keep things as short as possible.
 */
void protocol_dispatch_message(uint8_t cmd, uint8_t *message, uint8_t length){
	if ((cmd& 0xF0) == 0x00){
		//General messages; do nothing here.
	}
	else if ((cmd& 0xF0) == 0x10){
		controller = CONTROLLER_UC;
	}
	else if ((cmd& 0xF0) == 0x20){
		controller = CONTROLLER_PROCESSING;
	}
	else if ((cmd& 0xF0) == 0x30){
		controller = CONTROLLER_CALIBRATION;
	}
	//TODO Put any other supported control modes here.
	else {
		controller = CONTROLLER_NONE;
	}
	
	if (cmd == MESSAGE_REQUEST_ENABLE_DEBUG){
		debug = 0x01;
		doAcknowledgeCommand(MESSAGE_REQUEST_ENABLE_DEBUG);
	}
	else if (cmd == MESSAGE_REQUEST_DISABLE_DEBUG){
		debug = 0x00;
		doAcknowledgeCommand(MESSAGE_REQUEST_DISABLE_DEBUG);
	}
	//This is a Universal Controller message (namespace 0x1X)
	else if (controller == CONTROLLER_UC && (cmd & 0xF0) == 0x10){
		uc_dispatch_message(cmd, message, length);
	}
	//This is a Processing API message (namespace 0x2X)
	else if (controller == CONTROLLER_PROCESSING && (cmd & 0xF0) == 0x20){
		processing_dispatch_message(cmd, message, length);
	}
	//This is a Calibration API message (namespace 0x3X)
	else if (controller == CONTROLLER_CALIBRATION && (cmd & 0xF0) == 0x30){
		calibration_dispatch_message(cmd, message, length);
	}
	else {
		//TODO Send debug message 'unknown command' or similar
	}
}

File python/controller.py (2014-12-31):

import sys
import pygame
import serial
import time
import os 

#Center the pygame window on screen
os.environ['SDL_VIDEO_CENTERED'] = '1'

ser = None

MESSAGE_ANNOUNCE_CONTROL_ID			=	0x00

MESSAGE_UC_BUTTON_PUSH				=	0x10
MESSAGE_UC_BUTTON_RELEASE			=	0x11
MESSAGE_UC_BUTTON_NONE				=	0x12
MESSAGE_UC_JOYSTICK_MOVE			=	0x13

CONTROLLER_BUTTON_VALUE_SELECT	=	0x00
CONTROLLER_BUTTON_VALUE_LEFT3	=	0x01
CONTROLLER_BUTTON_VALUE_RIGHT3	=	0x02
CONTROLLER_BUTTON_VALUE_START	=	0x03
CONTROLLER_BUTTON_VALUE_PADUP	=	0x04
CONTROLLER_BUTTON_VALUE_PADRIGHT=	0x05
CONTROLLER_BUTTON_VALUE_PADDOWN	=	0x06
CONTROLLER_BUTTON_VALUE_PADLEFT	=	0x07
CONTROLLER_BUTTON_VALUE_LEFT2	=	0x08
CONTROLLER_BUTTON_VALUE_RIGHT2	=	0x09
CONTROLLER_BUTTON_VALUE_LEFT1	=	0x0A
CONTROLLER_BUTTON_VALUE_RIGHT1	=	0x0B
CONTROLLER_BUTTON_VALUE_TRIANGLE=	0x0C
CONTROLLER_BUTTON_VALUE_CIRCLE	=	0x0D
CONTROLLER_BUTTON_VALUE_CROSS	=	0x0E
CONTROLLER_BUTTON_VALUE_SQUARE	=	0x0F

def write(command, message):
	'''
	Write the given command + message to the serial port.  The command MUST be a single unsigned byte between 0 and 255.  
	The message MUST be a list of numbers between 0x00 and 0xFF.
	'''
	START = 0x7e
	ESCAPE = 0x7d
	
	def append_byte(data, b, escape=True):
		if (escape and (b == chr(START) or b == chr(ESCAPE))):
			data.append(chr(ESCAPE))
			data.append(chr(b ^ 0x20))
		else:
			data.append(chr(b))

	data = [chr(START)]
	append_byte(data, len(message) + 1)
	append_byte(data, command)
	
	checksum = command
	for b in message:
		checksum = (checksum + b) & 0xFF
		data.append(chr(b))
		
	append_byte(data, (0xFF - checksum))
	
	print(data)
	for b in data:
		print(hex(ord(b)))
		ser.write(b)

def keyboard_listener():
	keys = {}
	
	while True:
		for event in pygame.event.get():
			# determine if X was clicked, or Ctrl+W or Alt+F4 was used 
			if event.type == pygame.QUIT:
				print("Quitting...")
				return
				
			if event.type == pygame.KEYDOWN or event.type == pygame.KEYUP:
				if event.key in [pygame.K_t, pygame.K_RCTRL, pygame.K_LCTRL]:
					if event.key == pygame.K_t:
						button_id = CONTROLLER_BUTTON_VALUE_START
					elif event.key == pygame.K_RCTRL:
						button_id = CONTROLLER_BUTTON_VALUE_RIGHT2
					elif event.key == pygame.K_LCTRL:
						button_id = CONTROLLER_BUTTON_VALUE_LEFT2
					
					if event.type == pygame.KEYDOWN:
						write(MESSAGE_UC_BUTTON_PUSH, [button_id])
					else:
						write(MESSAGE_UC_BUTTON_RELEASE, [button_id])
					
					
				if event.key in [pygame.K_LEFT, pygame.K_RIGHT, pygame.K_UP, pygame.K_DOWN, pygame.K_a, pygame.K_s, pygame.K_d, pygame.K_w]:
					if event.type == pygame.KEYDOWN:
						keys[event.key] = True
					else:
						del keys[event.key]
				
					if pygame.K_a in keys:
						left_x = 0
					elif pygame.K_d in keys:
						left_x = 255
					else:
						left_x = 128

					if pygame.K_w in keys:
						left_y = 0
					elif pygame.K_s in keys:
						left_y = 255
					else:
						left_y = 128
						
					if pygame.K_LEFT in keys:
						right_x = 0
					elif pygame.K_RIGHT in keys:
						right_x = 255
					else:
						right_x = 128

					if pygame.K_UP in keys:
						right_y = 0
					elif pygame.K_DOWN in keys:
						right_y = 255
					else:
						right_y = 128
					
					write(MESSAGE_ANNOUNCE_CONTROL_ID, [ord('U')])
				
					analog = [left_x, left_y, right_x, right_y]
					write(MESSAGE_UC_JOYSTICK_MOVE, analog)
					print(keys)
					
			
				

########## Main startup hooks here ##########
if (__name__=="__main__"):
	if (len(sys.argv) != 2):
		print("Usage: " + sys.argv[0] + " <port>")
		sys.exit(0)

	ser = serial.Serial(sys.argv[1], 38400, timeout=1)
	
	pygame.init()
	pygame.display.set_mode([320, 200])
	pygame.key.set_repeat(1, 500) #No delay, 500ms interval
	
	write(MESSAGE_ANNOUNCE_CONTROL_ID, [ord('U')])
	
	keyboard_listener()

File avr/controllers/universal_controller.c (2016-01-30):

#include "universal_controller.h"

extern Leg legs[LEG_COUNT];

static volatile uc_stick_t left_stick;
static volatile uc_stick_t right_stick;

static volatile uint16_t uc_buttons_pressed;
static volatile uint16_t uc_buttons_released;
static volatile uint16_t uc_buttons_held;

uint16_t uc_read_pressed_buttons(){
	if (uc_buttons_pressed == 0x00) return 0x00;
	
	uint16_t result = uc_buttons_pressed;
	uc_buttons_pressed = 0x00;
	return result;
}

uint16_t uc_read_released_buttons(){
	if (uc_buttons_released == 0x00) return 0x00;
	
	uint16_t result = uc_buttons_released;
	uc_buttons_released = 0x00;
	return result;
}

uint16_t uc_read_held_buttons(){
	return uc_buttons_held;
}

uc_stick_t uc_read_left(){
	uc_stick_t result;
	result.x = left_stick.x;
	result.y = left_stick.y;
	return result;
}
uc_stick_t uc_read_right(){
	uc_stick_t result;
	result.x = right_stick.x;
	result.y = right_stick.y;
	return result;
}

void uc_remote_control(){
	pwm_start();
	status_set_color(0x00, 0xFF, 0x00);
	battery_enable_status();
	doResetLegs();
	
	//Hit Start to exit remote control mode, and go back to startup
	while(1){
		wdt_reset();
		
		//Exit when start is pressed again (or if UC loses controller state)
		if (!(get_power() & POWER_ON)){
			break;
		}
		else if (get_controller() != CONTROLLER_UC){
			break;
		}

		
		uint16_t buttons_pressed = uc_read_pressed_buttons();
		uint16_t buttons_held = uc_read_held_buttons();
		uc_stick_t left_stick = uc_read_left();
		uc_stick_t right_stick = uc_read_right();

		if (buttons_pressed & _BV(CONTROLLER_BUTTON_VALUE_CROSS)){
			doResetLegs();
		}
		//Translation: XY (left stick) and Z (right stick)
		else if (buttons_held & _BV(CONTROLLER_BUTTON_VALUE_LEFT2)){
			uint16_t x = left_stick.x * -0.2;
			uint16_t y = left_stick.y * -0.2;
			uint16_t z = (right_stick.y > 50 || right_stick.y < -50) ? right_stick.y * -0.1 : 0;

			for (uint8_t l = 0; l < LEG_COUNT; l++){
				Point translate(x, y, z);
				legs[l].setOffset(translate);
			}
			
			pwm_apply_batch();
#if F_CPU == 12000000
			delay_ms(5);
#elif F_CPU == 18432000
			delay_ms(8);
#elif F_CPU == 20000000
			delay_ms(10);
#else
#warning Non-standard CPU speed.  Please specify a delay.
#endif
		}
		//Rotation: Pitch / Roll (left stick) and Yaw (right stick)
		else if (buttons_held & _BV(CONTROLLER_BUTTON_VALUE_RIGHT2)){
			//We get the magic number of 1440 by multiplying 180 by 8... it is identical to saying right_stick.x / 8 * (M_PI / 180), but faster
			double pitch = left_stick.y * M_PI / 1440;
			double roll = left_stick.x * -M_PI / 1440;
			double yaw = right_stick.x * M_PI / 1440;
			
			for (uint8_t l = 0; l < LEG_COUNT; l++){
				legs[l].setOffset(Point(0,0,0));
				Point p = legs[l].getPosition();
				p.rotateXY(yaw);	
				p.rotateYZ(pitch);
				p.rotateXZ(roll);
				legs[l].setPosition(p);
			}
			
			pwm_apply_batch();
#if F_CPU == 12000000
			delay_ms(5);
#elif F_CPU == 18432000
			delay_ms(8);
#elif F_CPU == 20000000
			delay_ms(10);
#else
#warning Non-standard CPU speed.  Please specify a delay.
#endif
		}
		//Normal movement
		else {
			double linear_angle = 0;
			if (left_stick.x == 0 && left_stick.y > 0){
				linear_angle = M_PI / 2;
			}
			else if (left_stick.x == 0 && left_stick.y < 0){
				linear_angle = M_PI / -2;
			}
			else if (left_stick.x != 0 || left_stick.y != 0){
				linear_angle = atan2(left_stick.y, left_stick.x);
			}

			//Use pythagorean theorem to find the velocity, in the range [0..1].
			double linear_velocity = fmin(1.0, fmax(0.0, sqrt((left_stick.x * left_stick.x) + (left_stick.y * left_stick.y)) / 127.0));
			
			//We only care about the X axis for right (rotational) stick
			double rotational_velocity = right_stick.x / 127.0;

			if (rotational_velocity <= 0.3 && rotational_velocity > -0.3) rotational_velocity = 0;
			if (linear_velocity <= 0.3) linear_velocity = 0;
			if (linear_velocity != 0 || rotational_velocity != 0){
				static int8_t step_index = 0;
				
				for (uint8_t l = 0; l < LEG_COUNT; l++){
					Point step = gait_step(legs[l], step_index, linear_velocity, linear_angle, rotational_velocity);
					legs[l].setOffset(step);
				}
				step_index++;
				if (step_index > gait_step_count()){
					step_index = 0;
				}
			}
			else {
				for (uint8_t l = 0; l < LEG_COUNT; l++){
					legs[l].setOffset(Point(0,0,0));
				}
			}
			pwm_apply_batch();
#if F_CPU == 12000000
			delay_ms(5);
#elif F_CPU == 18432000
			delay_ms(7);
#elif F_CPU == 20000000
			delay_ms(8);
#else
#warning Non-standard CPU speed.  Please specify a delay.
#endif

		}
	}
	
	battery_disable_status();
	doResetLegs();
	status_set_color(0x00, 0x00, 0x00);
	delay_ms(200);

	pwm_stop();
}

/*
 * Calibration mode.  Use the following buttons to calibrate:
 *  -Square switches between legs.  As a new leg is selected, flash the leg color on the status LED.
 *  -Left / Right adjusts coxa joint for selected leg
 *  -Up / Down adjusts femur joint for selected leg
 *  -L1 / L2 adjusts tibia joint for selected leg
 *  -Circle + Triangle resets all values back to 0 (flash red)
 *  -Triangle by itself resets all values back to last saved (flash yellow)
 *  -Cross by itself saves changes to EEPROM (flash green)
 *  -Start exits calibration mode, discarding unsaved changes
 */
void uc_calibration(){
	pwm_start();

	status_flash(0x00, 0x00, 0xFF, 5);
	uint8_t l = 0;
	uint8_t mode = 0x00;		//switch between calibration modes: neutral angle offset (for joint calibration), and position calibration (for X,Y,Z positioning calibration)
	
	//We calibrate against the servos in neutral phase, trying to match the angles as stated in Leg.h:
	// TIBIA_NEUTRAL_SERVO_ANGLE, FEMUR_NEUTRAL_SERVO_ANGLE, and MOUNTING_ANGLE (yeah, coxa is different
	// from the others).
	for (uint8_t l = 0; l < LEG_COUNT; l++){
		for (uint8_t j = 0; j < JOINT_COUNT; j++){
			pwm_set_phase_batch(l * JOINT_COUNT + j, PHASE_NEUTRAL + (legs[l].getCalibration(j) * 10));
		}
	}
	pwm_apply_batch();
	
	//Loop until Start is pressed (or UC loses controller state)
	while (1){
		wdt_reset();
		
		delay_ms(20);
		
		uint16_t buttons_pressed = uc_read_pressed_buttons();
		
		if (buttons_pressed != 0x00){
			//Start exits calibration mode (whether or not changes were made / applied / saved).
			if (buttons_pressed & _BV(CONTROLLER_BUTTON_VALUE_START)){
				break;
			}
			else if (get_controller() != CONTROLLER_UC){
				break;
			}

			//Blink lights out every button press
			status_set_color(0x00, 0x00, 0x00);
			delay_ms(60);
			
			//Select changes modes.  Flash 5 purple for mode == 1, 5 blue for mode == 0.
			if ((buttons_pressed & _BV(CONTROLLER_BUTTON_VALUE_SELECT)) != 0) {
				mode ^= 0x01;
				status_flash((mode ? 0xFF : 0x00), 0x00, 0xFF, 5);
			}
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

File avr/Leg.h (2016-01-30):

#ifndef LEG_H
#define LEG_H

#ifndef DEBUG_SIMULATION
#include <avr/io.h>
#include "lib/pwm/pwm.h"
#else
#include <stdlib.h>
#include <stdint.h>
#include <stdio.h>
#include "../simulation/debug.h"
#endif
#include "types/Point.h"

#include "Stubby.h"

//*** See doc/diagrams.pdf for figure x.y references ***//


//The distance from 0,0 at which legs are mounted.  This assumes a radial symmetry of all legs (i.e. the distance
// is the same for all the legs); if this does not apply to your design, you will need to pass in an x,y offset for
// each leg in its constructor, and modify the translation function to use it.  See figure 1.1, 'leg offset'
#define LEG_OFFSET						45
//The angle offset for a single leg.  All legs are defined as a multiple of this number.  For the current design
// (radial symmetry, with the middle leg sticking straight out the side) this should be 60 degrees.  See
// figure 1.1, 'mounting angle'.
#define LEG_MOUNTING_ANGLE				(60 * M_PI / 180)

//The height from ground to the center of the coxa joint.  See figure 1.2, 'coxa height'.
#define COXA_HEIGHT						55.0
//The length of the leg segment between coxa and femur joints (measured between center of each joint).  See
// figure 1.2, 'coxa length'
#define COXA_LENGTH						49.0
//The height from the center of the coxa joint to the center of the femur joint.  See figure 1.2, 'femur height'.
#define FEMUR_HEIGHT					17.825
//The length of the leg segment between femur and tibia joints (measured between center of each joint).  See
// figure 1.2, 'femur length'
#define FEMUR_LENGTH					40.0
//The length of the leg segment between tibia joint and end of the foot (measured from the center of the joint)
// See figure 1.2, 'tibia length'
#define TIBIA_LENGTH					57.0


//The lengths of the four segments in the Tibia drive system.  See figure 1.3, segments a, b, c and d.
#define TIBIA_A							30.0
#define TIBIA_B							16.3
#define TIBIA_C							54.0
#define TIBIA_D							34.0
//The difference in angle between the desired angle and the angle between segments d and a.  See
// figure 1.3, angle 'E'
#define TIBIA_E_OFFSET_ANGLE			(20 * M_PI / 180)
//The angle at which the servo horn extends from the servo when a neutral PWM signal is applied.  See
// figure 1.3, angle 'N'
#define TIBIA_NEUTRAL_SERVO_ANGLE		(135 * M_PI / 180)

//The lengths of the four segments in the Femur drive system.  See figure 1.4, segments a, b, c and d.
#define FEMUR_A							27.7
#define FEMUR_B							16.5
#define FEMUR_C							38.5
#define FEMUR_D							34.0
//The difference in angle between the desired angle and the angle between segments d and a.  See
// figure 1.4, angle 'E'
#define FEMUR_E_OFFSET_ANGLE			(31.5 * M_PI / 180)
//The angle at which the servo horn extends from the servo when a neutral PWM signal is applied.  See
// figure 1.4, angle 'N'
#define FEMUR_NEUTRAL_SERVO_ANGLE		(135 * M_PI / 180)

//For the Coxa joint we just use a linear equation to determine the offsets, since it is close enough for
// most purposes and eliminates a lot of math needed for the drive system calculations.  To determine
// this value, set the coxa joint on a single leg to various phases (for instance, 1500 + 300, 1500 - 300, 
// 1500 + 600, etc) and measure the resulting angles.  On my robot, I get approx. 16 degrees for each
// phase offset of 300us.  By dividing this out (300 / (16 * PI / 180)) I get the value 1074.296, which 
// means that for each radian I want to move, I adjust the phase by 1074.296.
#define COXA_PHASE_MULTIPLIER			-1074.296

//Servo travel information.  We assume a neutral offset of 1500, with even amounts on either side.  We also assume that the servo has 
// a linear travel between one end and the other.
#define PHASE_MIN						700			//Clockwise from neutral
#define PHASE_NEUTRAL					1500
#define PHASE_MAX						2300		//Counter clockwise from neutral

//Maximum angle of travel for the servo, in radians (between MIN_PHASE and MAX_PHASE).  Therefore, the maximum 
// travel in each direction from neutral is half of this number.
#define SERVO_TRAVEL					(150 * M_PI / 180)

/*
	* C++ implementation of Stubby the Hexapod leg.
	*/
class Leg {
	private:
		uint8_t index;
		
		volatile uint8_t *port[JOINT_COUNT];
		uint8_t pin[JOINT_COUNT];

		Point p;										//Foot co-ordinates
		Point neutralP;									//Neutral foot co-ordinates
		double mounting_angle;							//The angle at which the leg is mounted, in degrees, relative to the X axis of a standard cartesian plane.
		int8_t calibration[CALIBRATION_COUNT];			//Calibration offset (in degrees for 0..2, and in mm for 3..5)
		
		//Set the angle for each servo.  This includes the servo abstraction code.
		void setTibiaAngle(double angle);
		void setFemurAngle(double angle);
		void setCoxaAngle(double angle);
		
	public:
		/*
		 * Initializes the leg, given the specified mounting angle describing it's radial position in degrees.
		 */
		Leg(uint8_t index, volatile uint8_t *tibia_port, uint8_t tibia_pin, volatile uint8_t *femur_port, uint8_t femur_pin, volatile uint8_t *coxa_port, uint8_t coxa_pin, double mounting_angle, Point neutralP);
		
		/*
		 * Set the foot position, relative to neutralP.
		 */
		void setOffset(Point offset);
		
		/*
		 * Resets the foot position to neutral (as defined from the constructor).
		 */
		void resetPosition();
		
		/*
		 * Returns the last set foot position.
		 */
		Point getPosition();

		/*
		 * Sets the foot position, in absolute x, y, z co-ordinates.  Performs the IK calculations, the absolute angle to servo angle calculations, and
		 * sets the servo position for each of the three joints.
		 */
		void setPosition(Point point);
		
		/*
		 * Gets the offset for the given joint
		 */
		int8_t getCalibration(uint8_t joint);
		
		/*
		 * Sets the offset for the given joint
		 */
		void setCalibration(uint8_t joint, int8_t offset);
		
		/*
		 * Returns the index
		 */
		uint8_t getIndex();
		
		/*
		 * Returns the mounting angle
		 */
		double getMountingAngle();
		
		/*
		 * Gets the specified port
		 */
		volatile uint8_t* getPort(uint8_t joint);
		
		/*
		 * Gets the specified pin
		 */
		uint8_t getPin(uint8_t joint);
};
#endif

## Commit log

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2014-05-24 Rev2 change to Stubby PCB: add + and - silkscreen on the reverse side
    [hex.kicad_pcb, hex.sch]
2014-05-24 Fixed program so that RGB LED now works. Added a status check using timer0 to allow repeated checking of different conditions (battery level, etc).
    [servo.c, status.c]
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2014-05-27 All MDF frame components for Stubby 3DOF now fit on a single 8.5x11 sheet of paper
    [frame_3dof_radial.dxf]
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2014-05-28 Set brownout detection at 2.7v, and preserve EEPROM through writes.
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2014-05-29 Adjust status to fix multiple bugs
    -Maximum brightness is now less than 100% duty cycle, so that the lights
    will turn off when set to 0 later
    -Fix timer enable / disable
    [status.c]
2014-05-29 Leg calibration is now more or less working
    -Each leg + joint can be configured in turn, and persisted to EEPROM (X)
    -Everything can be reset (Triangle)
    -Legs are iterated via Circle
    -Coxa, Femur, and Tibia joints are adjusted using Left/Right, Up/Down,
    and L1/L2 buttons respectively
    [calibration.c]
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2014-06-01 Something is not working properly...
    [Leg.cpp, Leg.h, Stubby.cpp]
2014-06-02 Adding three big capacitors to Stubby PCB (1 on 3v3 line to protect against brownouts caused by excessive servo current draw, 2 on the switched battery line)
    [hex.kicad_pcb, hex.sch]
2014-06-02 Bug fixes to Stubby C++ version. Still very much a WIP. Currently working on code to convert leg angle set point to servo PWM pulses, given a trapezoidal servo drive mechanism.
    [Leg.cpp, Leg.h, Stubby.cpp]
2014-06-02 Found bug; setting absolute tibia angle is now working as expected. Next step is to finish the same code for femur and coxa.
    [Leg.cpp, Leg.h, Stubby.cpp]
2014-06-03 Still WIP. All joints seem to be (somewhat) correct, but there is still some error in the output, and setPosition(x,y,z) doesn't seem to give the proper results either.
    [Leg.cpp, Leg.h, Stubby.cpp]
2014-06-03 Adding some debugging code and a simulator main function to help debug issues.
    [Leg.cpp, Leg.h, Main.cpp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]
2014-06-03 Working on diagrams to help figure out what is going wrong here...
    [frame_3dof_radial.dxf]
2014-06-04 Multiple changes and bugfixes, but still not quite working
    A few changes of note:
    -Split off a new drawing of diagrams to help explain the trigonometry
    which is required for the various calculations.
    -Referenced the above drawings (by figure number) in the source code.
    Roughly, figures 1.x are used to understand how to measure the
    constants, and figures 2.x are used to understand how the IK
    calculations are being obtained.
    -Designed a test program which (should) move all legs in synch from the
    front of their range of motion to the back (along the y axis), keeping
    the x and z values constant. (It doesn't work currently...)
    -Some more work on the simulator (including allowing it to compile un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
    [frame_3dof_radial.dxf, frame_3dof_radial_diagrams.dxf]
2014-06-04 Change fuses to use full swing oscillator (higher current draw, but more stable in noisy environments) and to take as long as possible to start up to allow voltage to stabilize.
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2014-06-05 IK is mostly working now...
    ... but the range of motion allowed by the servos is not enough to allow
    useful movements. (I converted the Coxa drive system to use the
    trapezoidal calculations and it is much better than just fuding the
    numbers as I was doing previously).
    [frame_3dof_radial.dxf, frame_3dof_radial_diagrams.dxf]
2014-06-05 Changing to a 50mm femur, from 20mm.
    Changed both the cutting diagram plus the associated measurements in the
    code. Things appear to be working much better with a longer femur;
    there is a much larger area which the foot can reach. The test program
    (moving along the Y axis) is not quite perfect, but it is pretty close
    to a straight line.
    Remaining to do: cut and attach the remaining new femurs, cut new
    control rods for tibia + femur, and triple check the measurements (I am
    pretty sure that the minor errors in the test program are due to
    inaccurate measurements somewhere).
    [frame_3dof_radial_diagrams.dxf]
2014-06-15 Updated leg.h with new control rod lengths. IK still not correct; perhaps invalid anles present.
    [Leg.h]
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2014-06-17 More confirmation of measurements. Something is still wrong in the actual movements; unsure if it is in the drive mechanism or in the IK calculations.
    [Leg.cpp, Main.cpp]
2014-06-17 mirrored the femur drive system diagram to match how it looks from the front (top of the servo).
    [frame_3dof_radial_diagrams.dxf]
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2014-06-17 Found a bug in the femur IK calculations which was messing things up. Fixed this bug, updated diagrams + simulation. Now to just try it out on the real robot...
    [frame_3dof_radial_diagrams.dxf, frame_3dof_radial_simulation.dxf]
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2014-06-18 Updated frame diagram to have PCB facing forward (rather than offset by 30 degrees)
    [frame_3dof_radial.dxf]
2014-06-18 Added another simulation of a non-zero-angle leg positioned within x,y,z space. From modeling the outputs in QCad, this appears to be working perfectly. I think the problem with the physical robot is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
    [frame_3dof_radial_simulation.dxf]
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2014-06-19 Updating trapezoidal drive calculation code + diagram to output correct servo angle offset.
    [frame_3dof_radial_diagrams.dxf]
2014-06-20 More WIP on trapezoidal drive system
    The tibias and femurs seem to be good now, but the coxas are now all
    wonky. I need to figure out what the neutral angle / E offset / desired
    angle needs to be this system...
    [frame_3dof_radial_diagrams.dxf]
2014-06-20 Fixing swapped ports for coxa / tibia on front left leg
    [Stubby.cpp]
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2014-06-20 Getting really close... all legs are moving as mirrors of the ones opposite them (which is good), but there is still something wrong with the calculations for the front and back legs; they seem to mo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
    [Main.cpp, Stubby.cpp]
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2014-06-28 Update to the frame; removed support bars, reduced the size of the middle layer, and rotated battery pack to align.
    [frame_3dof_radial.dxf]
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2014-06-28 Fix negative z offset bounds
    [Leg.cpp]
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2014-06-29 Re-added non-rotating braces between PCB, servo, and batter layers on the frame
    [frame_3dof_radial.dxf]
2014-06-29 Change to calibration
    We now calibrate against the servo neutral angle (rather than the
    desired angle). The raw value which is stored in EEPROM is multiplied
    by 10 and added to the neutral phase when setting the leg positions. To
    find the correct angle to calibrate against, look in Leg.h for the servo
    neutral values.
    [Leg.cpp, Stubby.cpp]
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2014-06-29 Overhaul of status
    Most notably, implementing the battery monitor. We use a running
    average (more correctly, a IIR - Infinite Impuse Response filter). We
    start the ADC once every overflow of timer0 (FCPU/1024) so as not to use
    too many cycles on a very low priority task.
    [Stubby.cpp, status.c]
2014-06-29 Starting to implement point rotation in 3D space on an arbitrary axis
    (but the code is not working yet).
    [Main.cpp]
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2014-06-30 Fix battery monitor
    Use a defined max / min battery ADC value, and fade status light between
    green and red based on battery level.
    [status.c]
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2014-07-04 Updated the frame diagram to show labels for each part (make assembly a bit easier as the web page can refer to labels)
    [frame_3dof_radial.dxf]
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2014-07-16 More work on TQFP Stubby. Unsure if the effort is worth it; the enhancements over rev1 are minimal.
    [hex.kicad_pcb, hex.sch]
2014-07-18 Restored rev1 Stubby board (into rev1 sub folder). Adding new rev2 board along side it (rev2 will not replace rev1; it is a different board with different capabilities, but which requires more diffic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
    [hex.kicad_pcb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]
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2014-07-21 Routed everything on Stubby rev2, and added a bluetooth + xbee breakout on the 5x5cm board
    [hex.kicad_pcb, hex.sch]
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2014-07-25 Rearranging rev2 still... something seems weird with the component association, may have to revert this commit.
    [hex.kicad_pcb, hex.sch]
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2014-07-25 Moved serial connector to the side... it still needs to move over to the left a bit more.
    [hex.kicad_pcb, hex.sch]
2014-07-29 Moved radio header over... should fit the XBee now (but still need to verify)
    [hex.kicad_pcb, hex.sch]
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2014-07-29 Added some more large value capacitors to 3v3 and 5v lines; changed battery meter to filter out lower frequency shifts (increased resistor + cap values); changed recommended i2c resistor values; mino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
    [hex.kicad_pcb, hex.sch]
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2014-07-29 Fix bug shorting out 3v3 to GND
    [hex.kicad_pcb, hex.sch]
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2014-07-30 Moved some components from the edge of the board / mounting holes, and added some small filtering capacitors for radio modules and AVR
    [hex.kicad_pcb, hex.sch]
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2014-08-28 Initial commit for Stubby / Processing interface
    The basic layout for a Processing library is included here, with an ant
    script which will build everything in the correct locations. The
    following features are supported so far:
    -Build the .zip file with 'ant' default task; unzip the resulting
    stubby.zip into "<Processing Sketch Root>/libraries" to show the new
    library under the "Sketch -> Import Library -> Stubby Control Interface"
    menu.
    -When making a sketch including Stubby control, you need to include the
    serial library as well
    -You can create a new Stubby instance using either the automatic serial
    port discovery (it connects to the first serial port containing 'stubby'
    in the name) or a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
    [Stubby.java]
2014-09-01 Changing stubby rev2 to have as many components on the top as possible to simplify manufacturing
    [hex.kicad_pcb]
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2014-09-01 Moved some more components to the front layer... now there are only four SMD components on the back (2x 100k for battery meter, and 2x 4.7k for I2C bus)
    [hex.kicad_pcb]
2014-09-01 Removed i2c resistors (they can be on whatever board you connect to Stubby); moved battery meter resistors to top of board. All SMD components are now on top to make manufacturing easier / cheaper
    [hex.kicad_pcb, hex.sch]
2014-09-01 Changed battery meter capacitor to be SMD (so as to not be in the way of the radio). Re-routed some traces to reduce via count. All components (SMD + through hole) are now on the top of the board.
    [hex.kicad_pcb, hex.sch]
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2014-09-02 WIP converting Stubby to use new protocol
    This is still very much a WIP, and in fact will not work at all at this
    moment (although it does compile). Currently it is expecting messages
    in the new protocol format from the universal controller; once the UC
    has been updated to send protocol messages, in theory it should work
    identically to how it worked before (i.e. the UC can control Stubby
    directly, but bluetooth control is not implemented). However there are
    likely additional bugs added during the conversion, so don't even count
    on it working as it did before... yet...
    [Stubby.cpp, Stubby.h, servo.c]
2014-09-02 Adjusted rev2 breakout boards to fit better on the board; verification and possibly more work still required.
    [hex.kicad_pcb]
2014-09-02 Reversed side for key
    [hex.kicad_pcb]
2014-09-03 Re-added edge cuts mistakenly deleted
    [hex.kicad_pcb]
2014-09-05 Adding the gerber files + zip which I ordered for Stubby rev2
    [hex-B_Cu.gbl, hex-B_Mask.gbs, hex-B_SilkS.gbo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]
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2014-09-07 Fixed some compile time errors
    [Stubby.cpp]
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2014-09-10 Bug fixes while working with Processing
    [Leg.h, Protocol.java, Stubby.cpp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]
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2014-09-10 Show battery before resetting legs (universal controller)
    [universal_controller.c]
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2014-09-11 -Committing the logic for the new Trig-based coxa servo calculations. I still need to measure the actual parts for the constant values, but have included approximations in this commit. -Updated the d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
    [frame_3dof_radial_diagrams.dxf]
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2014-09-12 -Re-added the simulation -Renamed trig.* to math.* (and added a sqrt_f function, although I am not yet sure if I will use it) -Fixed actual measurements for COXA_X and other Coxa measurements in Leg.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
    [frame_3dof_radial_diagrams.dxf]
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2014-09-13 Revert recent changes to coxa PWM; back to linear angles rather than trig-generated angles. Very little difference in practice, and the trig is noticeably slower.
    [Leg.cpp, Leg.h]
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2014-09-15 Adding a top layer for rev2.0 PCB (includes changes to the mounting holes plus space for the Sparkfun magnetometer).
    [frame_3dof_radial.dxf]
2014-09-17 Changed frame diagram to use Adafruit magnetometer rather than Sparkfun one... this is a better board, with faster shipping, for the same total amount.
    [frame_3dof_radial.dxf]
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2014-09-22 Work on rev 2.1... although the more I do it, the more I think it makes sense to just drop it all for now.
    [hex.kicad_pcb, hex.sch]
2014-09-24 Finished routing stubby rev2.1 (with magnetometer + reset button). Still could probably use some TLC, the routing around the magnetometer is pretty ugly.
    [hex.kicad_pcb, hex.sch]
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2014-09-26 Adding preliminary support for magnetometer to Stubby
    Basic support is here now... when an API call is made to move in a line,
    we check the current heading. While walking, we then compare the
    current heading with the initial heading, and correct as needed.
    Initial tests are promising, but there is still a lot of work to do:
    -Refactor processing API and protocol to separate move and turn
    (programming a veering move would be confusing at best, and it makes the
    auto-correcting heading difficult to program)
    -Add debug messages to the protocol, and start sending debug info on the
    heading correction to verify what is happening
    -Possibly look at calibrating the magnetometer on-board stubby (may no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
    [Stubby.cpp, Stubby.h, processing.c]
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2014-09-28 fixed bug in calcuating the angle between two vectors
    [processing.c]
2014-09-28 reset legs when using UC after joysticks stopped
    [universal_controller.c]
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2014-09-29 Remove all _delay_ms() calls from Stubby, and replace them with a custom delay function which looks at various mailbox flags and executes non-time sensitive code. These mailbox flags are set from ISR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
    Another advantage of this is that we now only use a single timer (timer2) to keep track of all of these low-frequency jobs, and all the supporting code is in the same place (hardware/timer2.c).
    This code has not yet been tested, but it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
    [Stubby.cpp, Stubby.h, battery.c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]
2014-09-30 fix some bugs in previous commit. Still not 100% working yet.
    [Stubby.cpp, battery.c]
2014-09-30 Added some test points on the board edge for i2c and serial (on rev 2.1)
    [hex.kicad_pcb, hex.sch]
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2014-09-30 Fix bug in status init
    [status.c]
2014-09-30 Fixed long standing bug in gait rotation code
    [Leg.cpp]
2014-09-30 Fix relative include paths (previously, it would work if the CWD was set to stubby/source, but would break as soon as you included a file from elsewhere, such as stubby/simulation).
    [battery.h]
2014-09-30 we no longer need to reverse y axis now that the rotation is correct
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2014-10-01 Added the concept of 'heading verification'
    This happens at the beginning of each heading-dependent operation (move,
    turn, etc). We repeatedly poll the magnetometer until we have a stable
    reading. We then use that reading as the set point for the following
    operation. This appears to work very well; for a short (maybe 0.5
    second) pause before each action, the accuracy of the action goes way
    up.
    [Stubby.cpp, processing.c]
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2014-10-03 Removed requirement to supply a baud rate (we know it is 38400); fixed a typo in a menu
    [calibration.py]
2014-10-03 More documentation for the python calibration program. It now includes (possibly too much) text describing what is happening and why.
    [calibration.py]
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2014-10-07 Moving some of the components around (most notably the 3.3v supply capacitor) to make assembly easier.
    [hex.kicad_pcb]
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2014-10-09 Improve mounting holes and reset button; move some vias from underneath pads
    [hex.kicad_pcb]
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2014-10-09 Changed to SMD capacitors for 3v3 and 5v reservoirs on 2.1... I am unsure of this change. The SMD caps are more expensive and harder to place, and so I had to put one of them on the bottom of the boa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
    [hex.kicad_pcb, hex.sch]
2014-10-10 Rev 2.1 board changes
    -Removed the resistor and zener from the AVR_RX / MODULE_TX trace. Now
    the module talks directly to the AVR without any interference (there
    were problems with my rev 2.0 board on this item...)
    -Compacted the SMD components a bit more
    [hex.kicad_pcb, hex.sch]
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2014-10-10 speed correction for processing controller
    [processing.c]
2014-10-10 Moving the 3v3 rail to another regulator, after the 5v one. In rev 2.0, the 5v output is very smooth while the 3v3 output is noisy; this causes the magnetometer to hang when the battery starts to get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
    [hex.kicad_pcb, hex.sch]
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2014-10-10 -Fix incorrect pinout in MCP1702 -Move some SMD components around for better fit
    [hex.kicad_pcb]
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2014-10-10 Change return type of getHeading from double to int.
    Integers give us more than good enough precision for degrees anyway.
    Tested previous changes; they do not work. Further testing is
    definitely needed, but no time right now.
    [Stubby.java]
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2014-10-15 Fixed bug in processing API which prevented headings from being processed
    [Protocol.java]
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2014-10-16 -Renamed hex.* to stubby.* (why I didn't do this sooner, who knows...) -Work on improving the continuity of the ground plane (back layer) -Moving all through hole capacitors to the back of the board,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
    [stubby.kicad_pcb, stubby.ods, stubby.sch]
2014-10-17 Fix minor misalignment on the tibia pieces as noticed by esistgut.
    [frame_3dof_radial.dxf]
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2014-11-16 Changes to processing controller:
    -Change doSendDebug(char* message, int length) to doSendDebug(char*
    message), with an automatically calculated length using strlen()
    -Re-arrange order of steps when doing a turn to ensure that heading
    confirmation is done before turn
    -trying to fix turning code to not overshoot (but still not working
    properly).
    [Stubby.cpp, Stubby.h, processing.c]
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2015-01-01 Reworking boost regulator routing
    [stubby.kicad_pcb]
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2015-01-07 Adjusted edge cuts based on results from latest board run; fixed ISP Edge solder mask issue
    [stubby.kicad_pcb]
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
